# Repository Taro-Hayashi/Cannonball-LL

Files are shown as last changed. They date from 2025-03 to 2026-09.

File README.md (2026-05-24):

# Cannonball LL Build Manual ([日本語](https://note.com/taro_hayashi/n/n3da1e116aa8d))

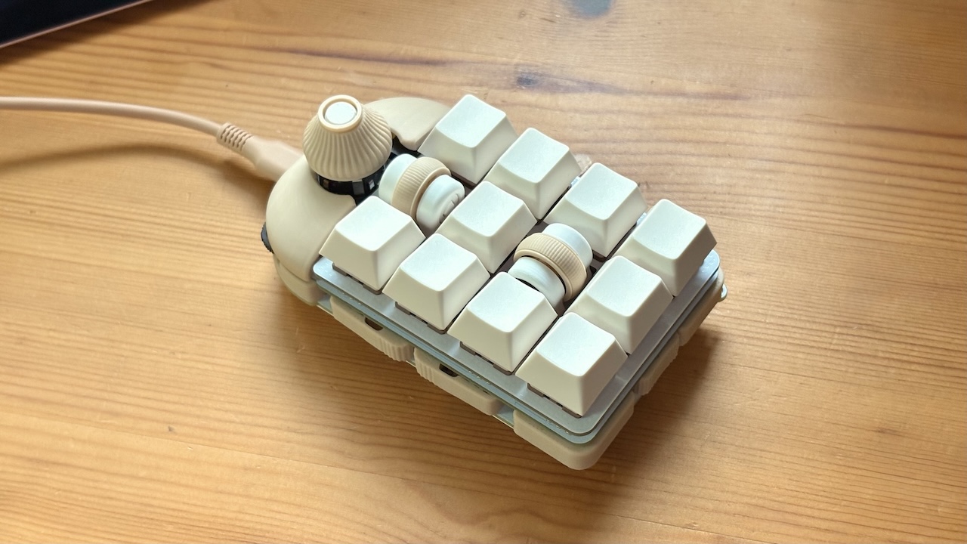
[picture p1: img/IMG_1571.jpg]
  

## 1 Introduction

### 1.1 Contents

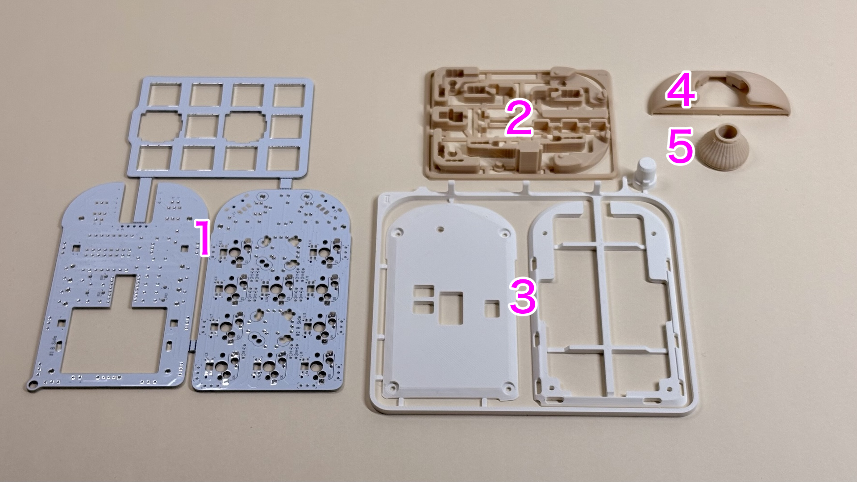
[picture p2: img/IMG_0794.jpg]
  
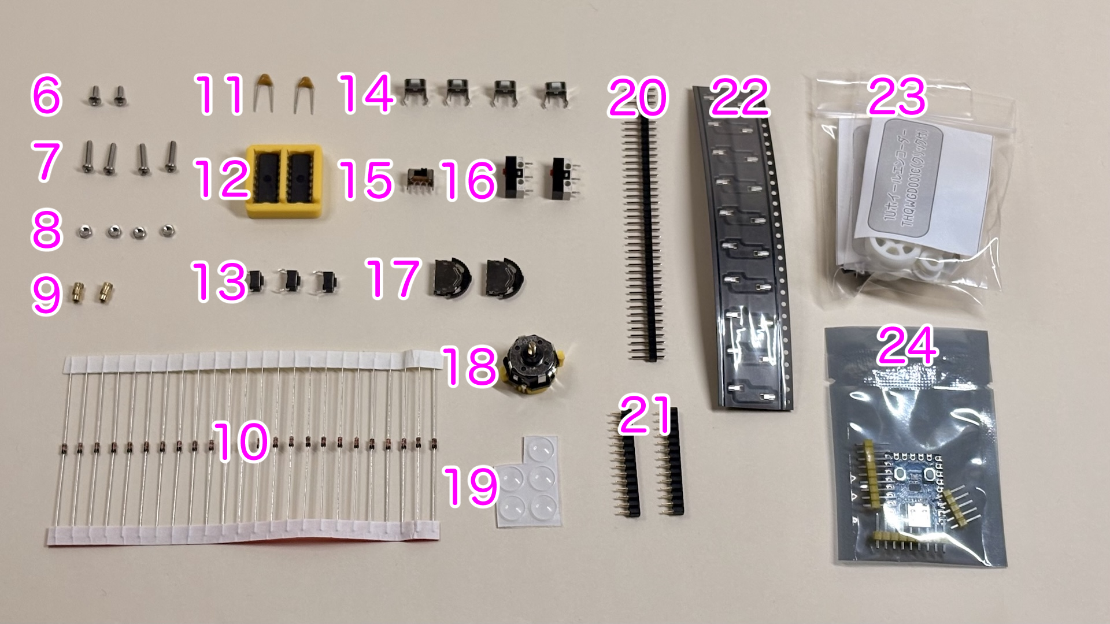
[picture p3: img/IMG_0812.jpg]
  

| | Types | Quantities | |
| --- | --- | --- | --- |
| 1 | PCB | 1 | |
| 2 | Runner I | 1 | |
| 3 | Runner II | 1 | |
| 4 | Top cover | 1 | |
| 5 | Knob cover | 1 | |
| 6 | Short screws | 2 | M2 6mm |
| 7 | Long screws | 4 | M2 10mm |
| 8 | Nuts | 4 | M2 |
| 9 | Insert nuts | 2 | M2 5mm or 6mm |
| 10  | Diodes | 24 | 1N4148 |
| 11  | Capacitors | 2 | 0.1uF |
| 12  | Shift registers | 2 | 74HC595 |
| 13  | back buttons | 3 | 3x6x4.3 |
| 14  | Side buttons | 4 | 3x6x5 |
| 15  | Slide switch | 1 | SK12F14 |
| 16  | Mouse buttons | 2 | YD-003 |
| 17  | Lever buttons | 2 | THMU27 |
| 18  | Rotary Encoder | 1 | RKJXT1F42001  |
| 19  | Rubber feet | 5 | |
| 20  | Pin header | 1 | 40pins |
| 21  | Pin Sockets | 2 | 14pins |
| 22  | Hotswap Sockets | 10 | CPG151101S11  |
| 23  | 1U Wheel Encoder | 2 | THQWGD001C |
| 24  | Micro Controller Board | 1 | RP2040-Zero |

### 1.2 Additional required

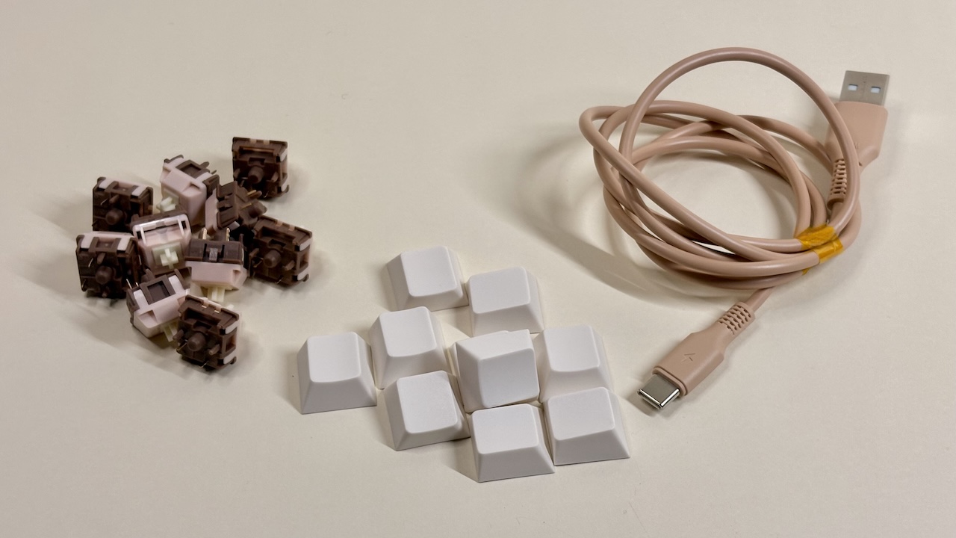
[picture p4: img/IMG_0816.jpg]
  

| Types | Quantities  |
| --- | --- |
| MX Keyswitches | 10  |
| Keycaps | 10  |
| Type-C USB cable | 1 |

### 1.3 Optional

See the guide below for more information on going wireless.
- [Cannonball LL Build Manual (wireless)](BLE.md)

| Types | Quantitie  | |
| --- | --- | --- |
| SK-6812MINI-E | 14  | |
| Choc V1/V2 keyswitches | 10  | Height can be reduced. Sockets and top plates are not used. It cannot coexist with MX switches. Not suitable for holding and using due to the possibility of short-circuiting as described below. |
| Tape or glue | 1 | When using Choc switches, isolate the head of the pin header to prevent unexpected operation. |
| [3-keys blocker](stl/) | 1 | Blocks the palm of the hand when held. |
| [Switch plate](stl/) | 1 | 3DP switch plate with invisible pin header heads. |
| Strap | | |

### 1.4 Tools required

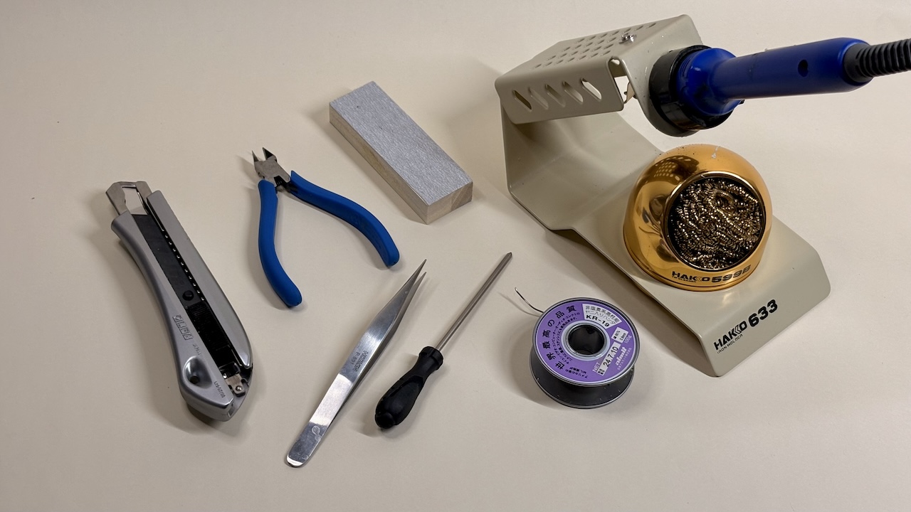
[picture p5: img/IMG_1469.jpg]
  

| Types                                                | 
| --------------------------------------------------- |
| Soldering iron                                               |
| Trowel                     |
| Soldering wire |
| Nipper                     | 
| Cutter                    |
| File                      | 
| Twezers                    |   
| screwdriver                 | 

### 1.5 Tools optional

| Types                               | 
| --------------------------------- | 
| C-type trowel tip                             | 
| flux|                    |
| IPA                               | 
| Heat-resistant mat                             | 
| Multimater                              |
| Desoldering wire                         | 
| Design Knife                           |
| Masking tape                          | 

## 2  Preparation for assembly

### 2.1 Disconnect the mainboard

It can be split cleanly by cutting a slit with a cutter and bending it.
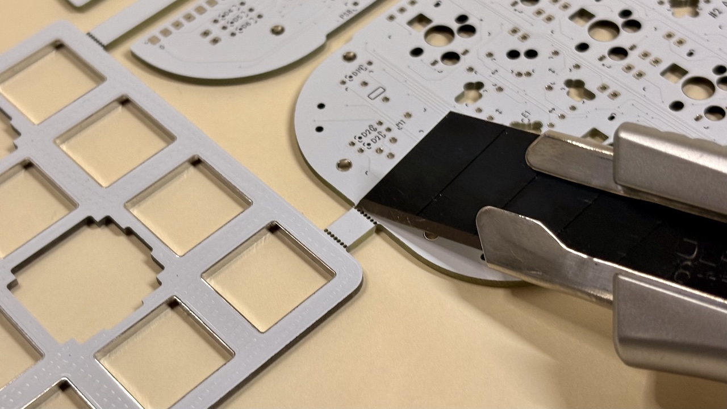
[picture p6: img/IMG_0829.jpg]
  
The tabs are cut away with nippers and the cut surfaces are sanded. Be careful not to remove the original board edges, as over-shaving will damage the circuitry.
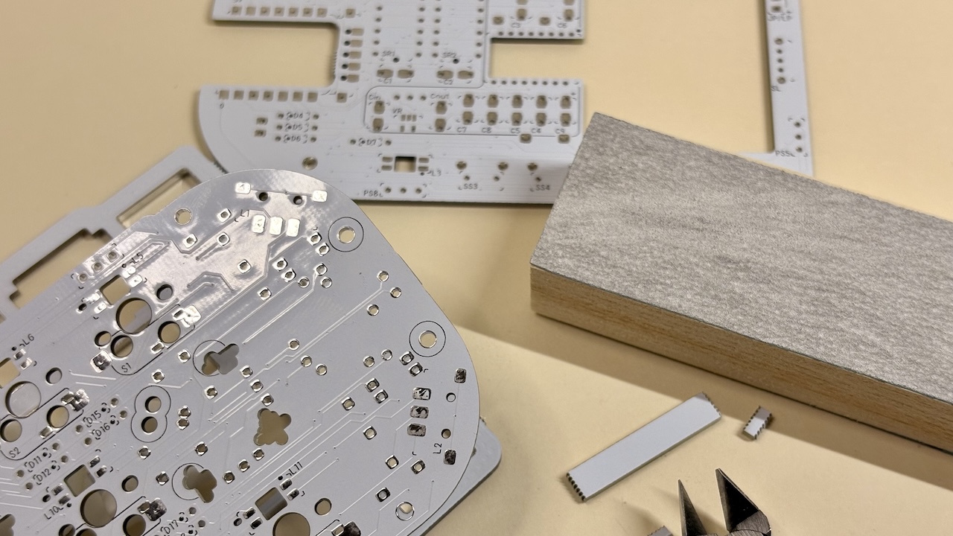
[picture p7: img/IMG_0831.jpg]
  
This area can be left jagged without affecting the finished form.
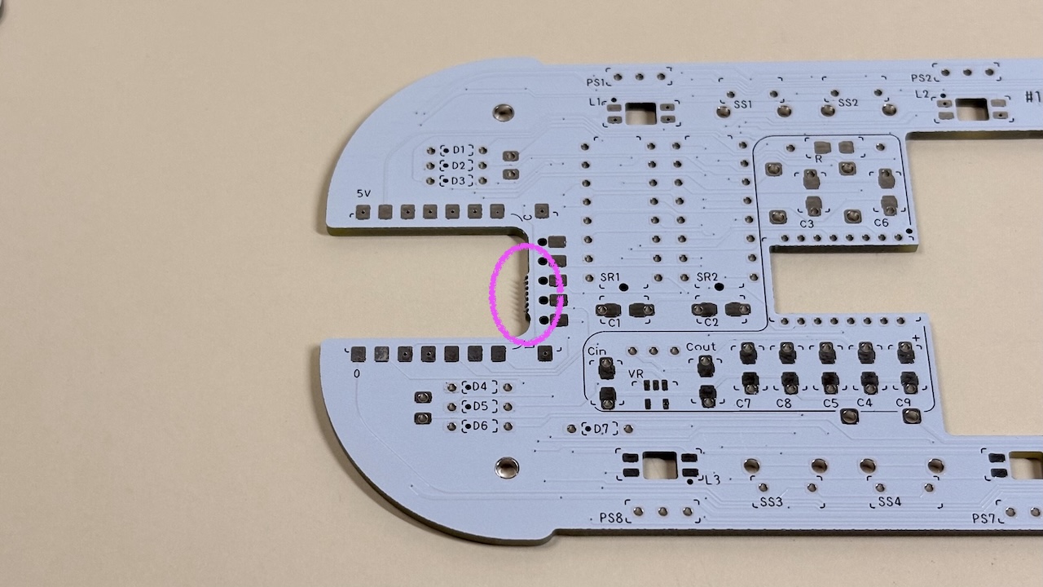
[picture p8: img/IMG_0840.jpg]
  
It could be divided into three parts: main board #1, main board #2 and switch plate.
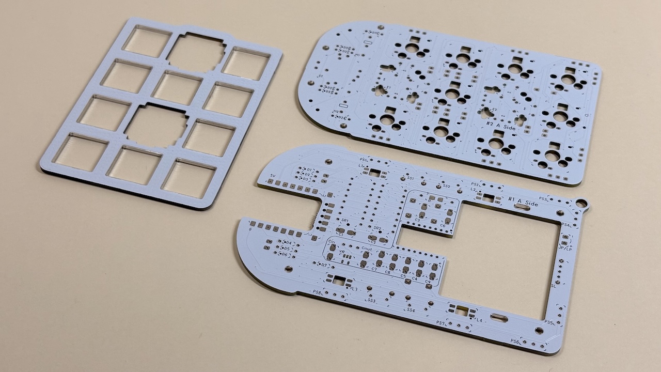
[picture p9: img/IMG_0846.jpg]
  

### 2.2 Remove parts from the runner

Runner I has 3 components and runner II has 17 components.
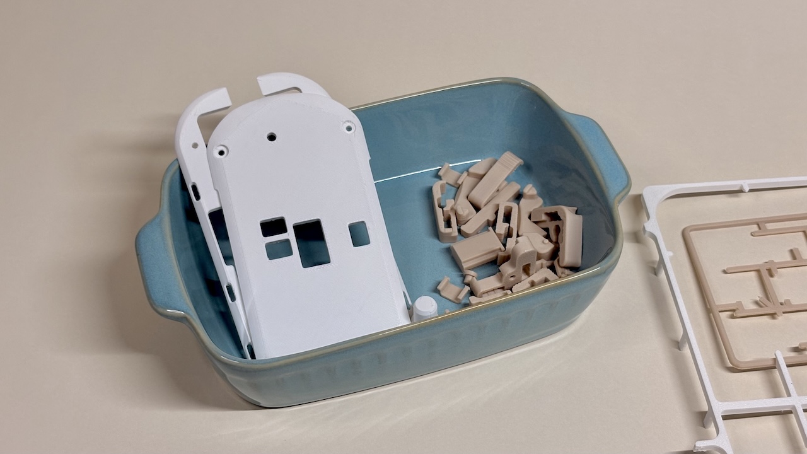
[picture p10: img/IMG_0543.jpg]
  

### 2.3 Remove the shift register and rotary encoder from the case

The shift register is pressed from the back with the runner II component (leverage). Be careful not to prick your finger with the pin.  
For the rotary encoder, cut the left and right claws with nippers.
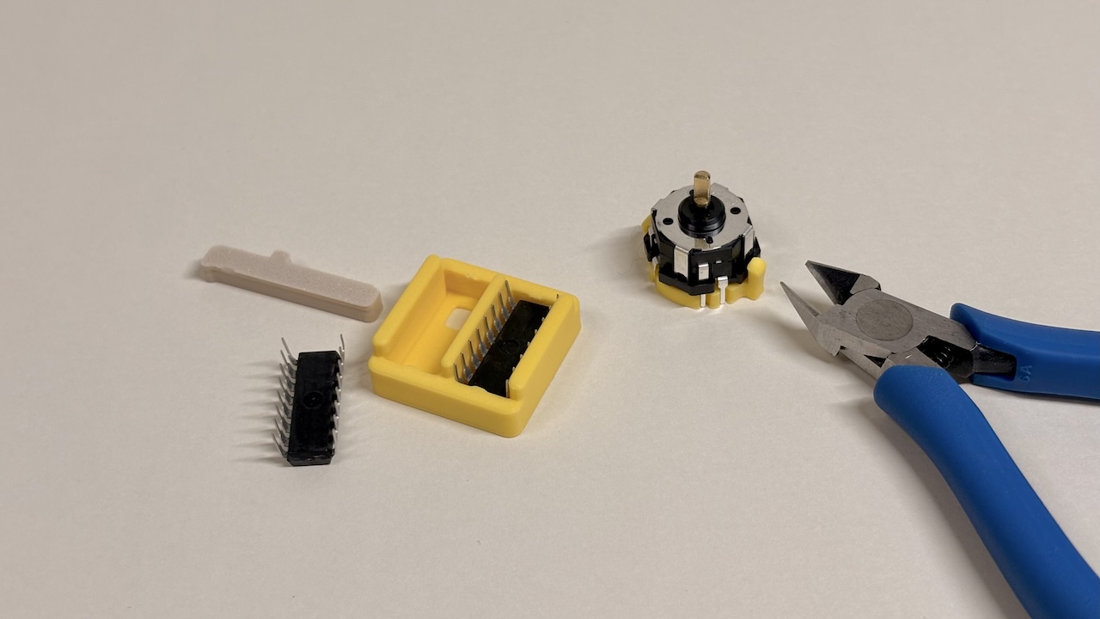
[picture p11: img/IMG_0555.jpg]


### 2.4 Write test firmware

Download the uf2 file here.

- [tarohayashi_cannonballll_default.uf2](https://github.com/Taro-Hayashi/Cannonball-LL/releases/latest/download/tarohayashi_cannonballll_default.uf2)

Connect to the PC via USB cable while pressing the BOOT button.
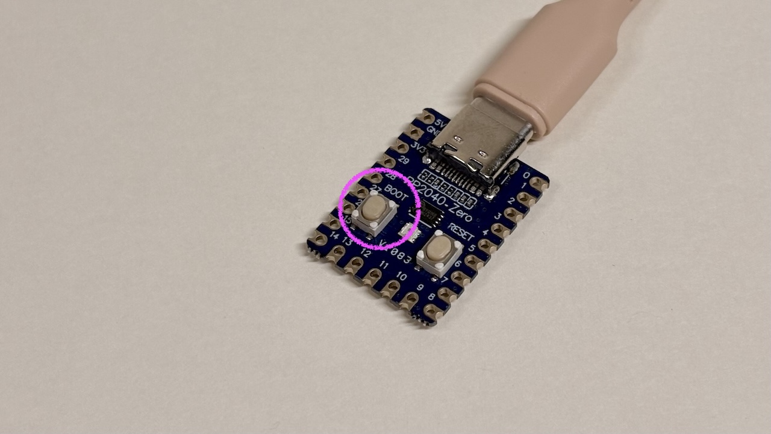
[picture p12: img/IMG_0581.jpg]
  
Drag and drop the uf2 file as it is recognised as an RPI-RP2 drive.  
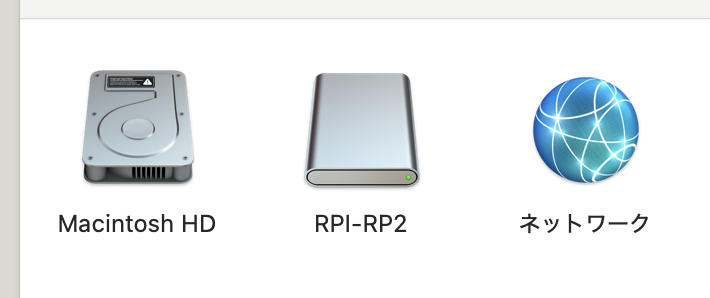
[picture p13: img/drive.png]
  
It will now be recognised as a keyboard.  

### 2.5 Press fitting of insert nuts

Press-fit the insert nut into the printed item in the image. Main board #1 is also used.
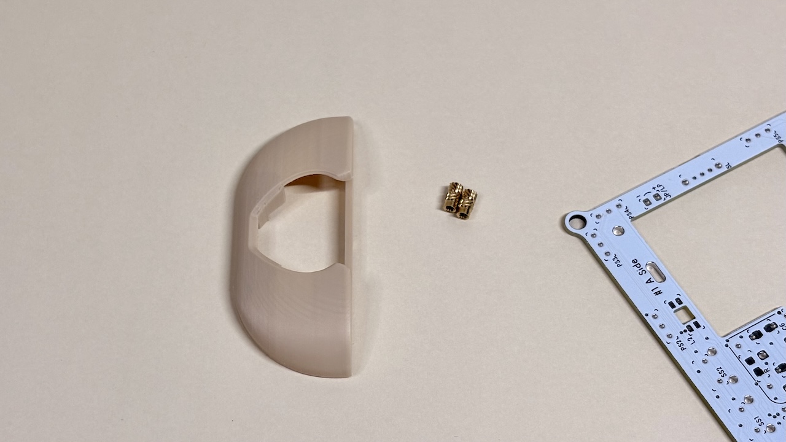
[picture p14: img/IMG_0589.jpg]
  
Apply main board #1 to the backside and press the soldering iron onto the insert nut.
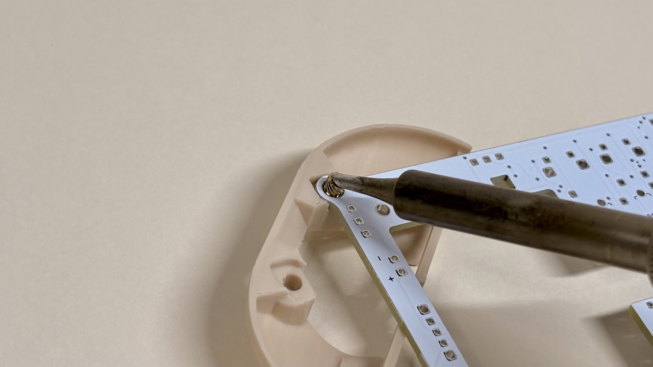
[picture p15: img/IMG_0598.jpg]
  
Ensure as few steps as possible with main board #1.
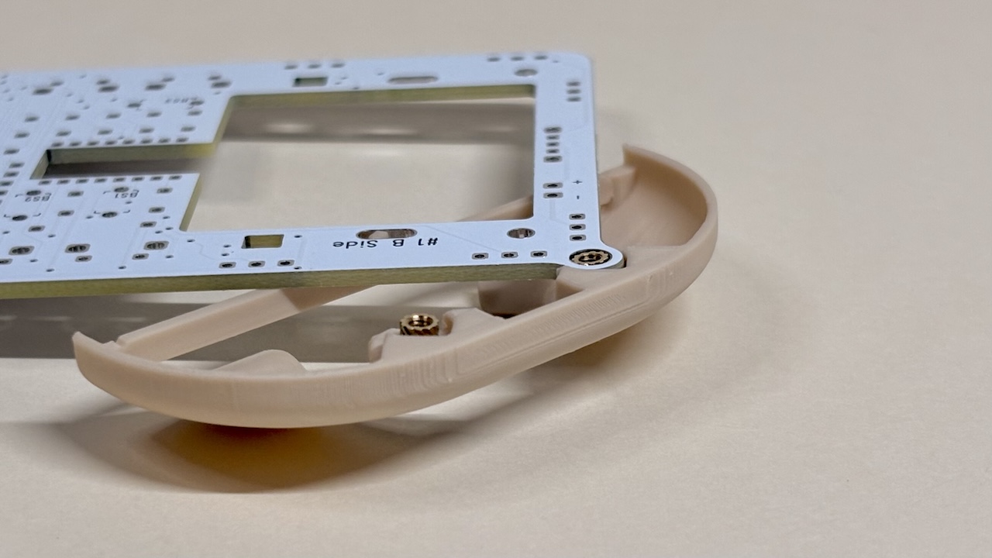
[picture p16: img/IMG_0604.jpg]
  
Cut out the reinforcement with nippers.
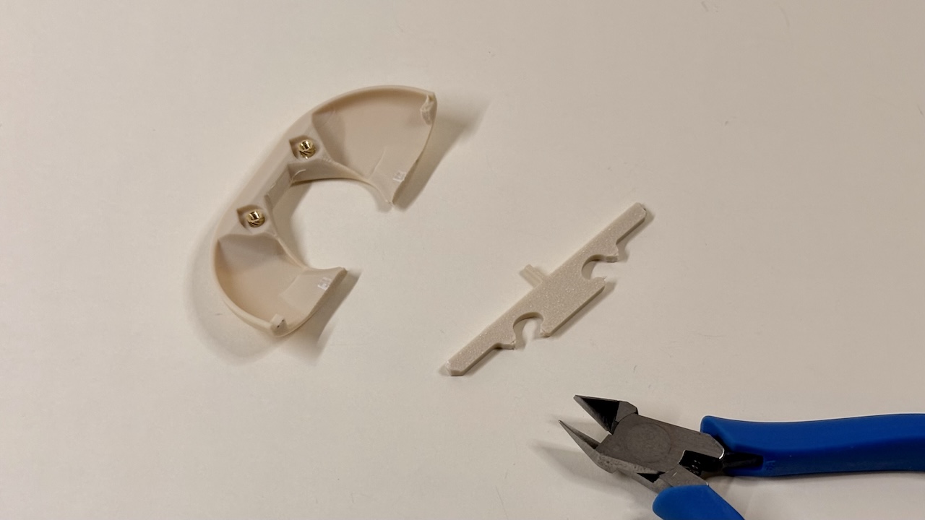
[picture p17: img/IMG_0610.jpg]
  

## 3 Soldering of main board #️1

### 3.1 Be careful when soldering

Imagine molten solder spreading only on the pad due to surface tension. It is very easy to apply flux.
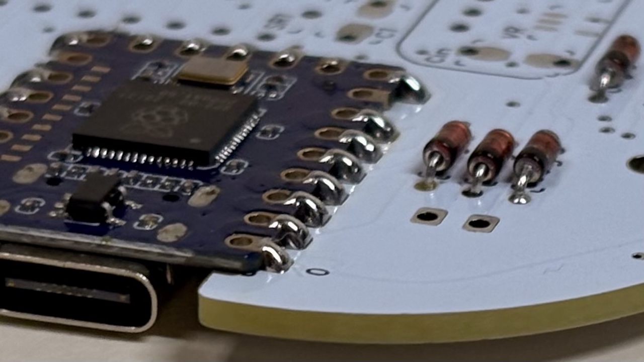
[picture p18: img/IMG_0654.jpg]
  
Heat the pads and component legs well to allow electricity to pass through both the board and the components.  
Be careful that the solder does not connect with the small holes (VIA).
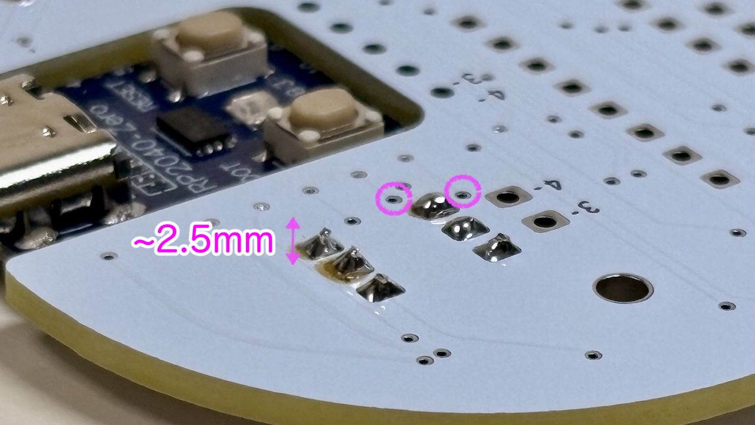
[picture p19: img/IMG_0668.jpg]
  
Take care that the legs coming out of the through-hole component are around 2 mm; if they exceed 2.5 mm, they may interfere with the 3D printed item on the bottom.  
It is easier to fix them with masking tape after insertion and soldering.
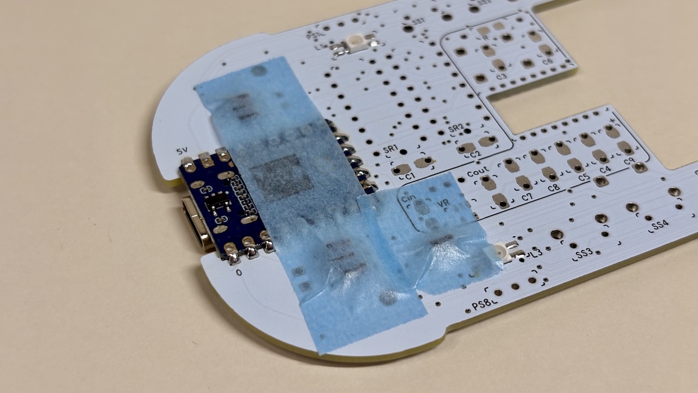
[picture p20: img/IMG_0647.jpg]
  
Also, the melting point of 3D printed products is around 200°C. Be careful not to melt the soldering iron if it comes into direct contact with it.

### 3.2 Soldering RP2040-Zero

Check the reverse side at 5V, GP0 and solder the 8 positions at the front once aligned using the pin headers supplied with the RP2040-Zero. Place a runner with the parts cut off underneath for stability.
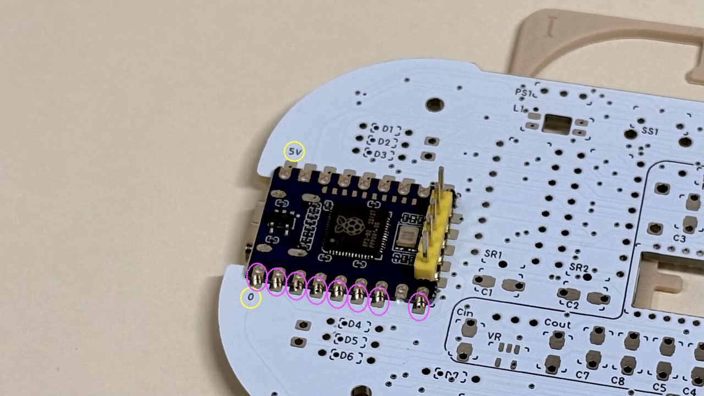
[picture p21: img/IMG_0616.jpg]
  
Once the other side is also soldered, remove the pin headers and solder the remaining five positions.
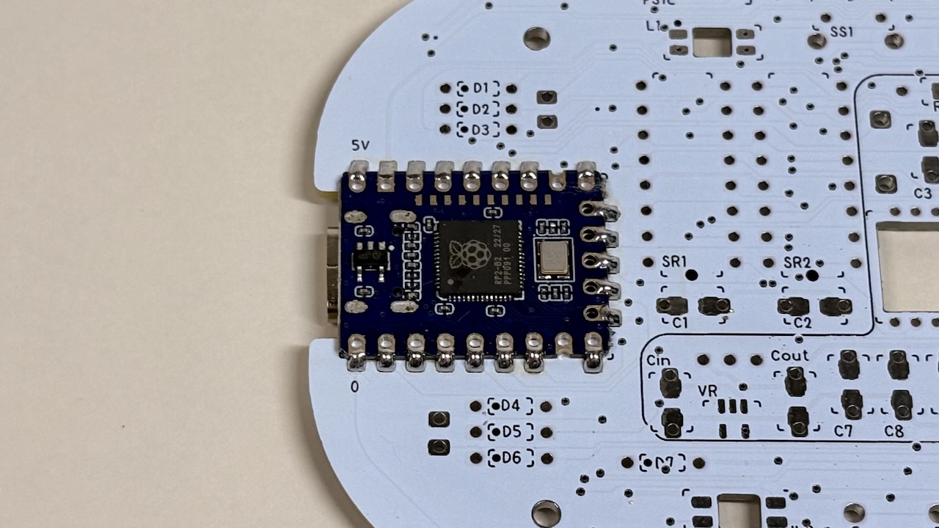
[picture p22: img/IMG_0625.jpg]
  

### 3.3 (Optional) Soldering the SK6812MINI-E

Solder L1 to L4, aligning the mark with the missing direction.
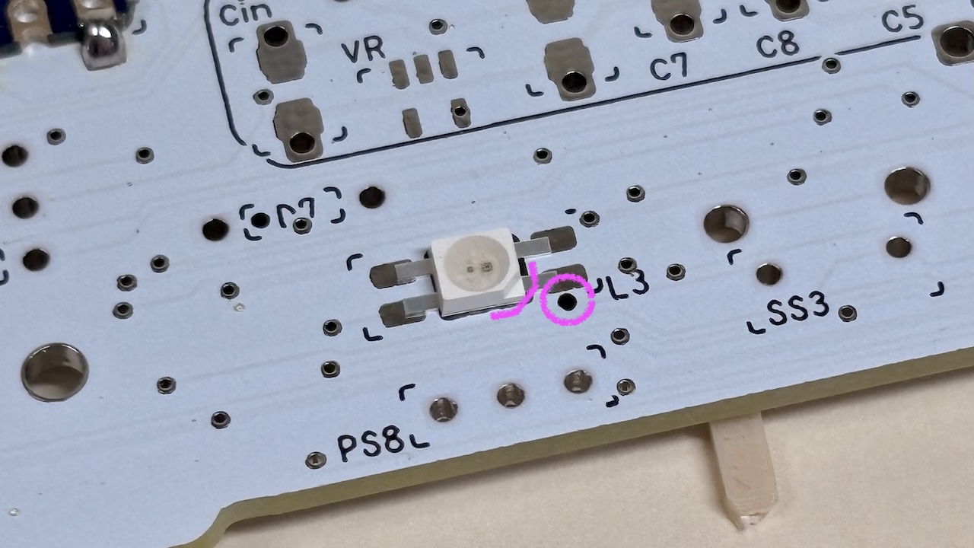
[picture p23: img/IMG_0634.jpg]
  
The luminous surface is facing you.
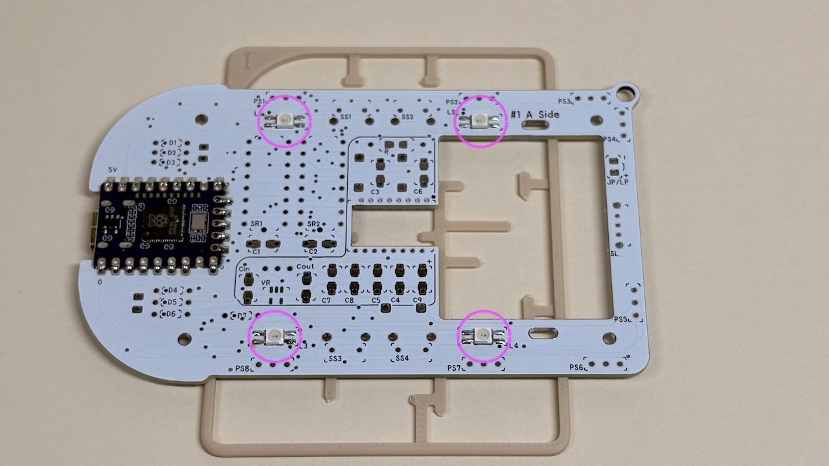
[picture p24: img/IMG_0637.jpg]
  

### 3.4 Soldering of diodes

The diode has a direction. Align the mark with the direction of the black line.
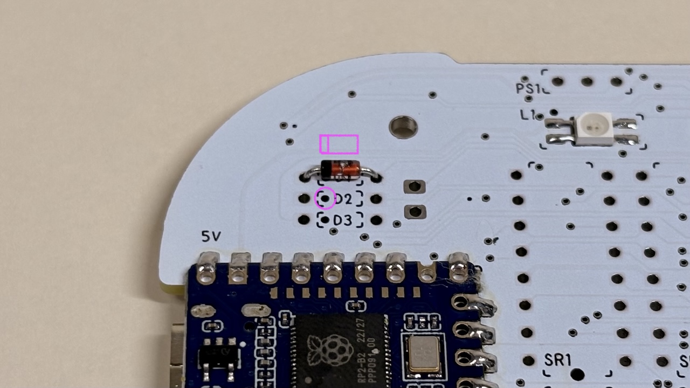
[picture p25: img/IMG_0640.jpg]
  
Insert the diode into D1, turn it over, solder it and cut the legs with nippers.
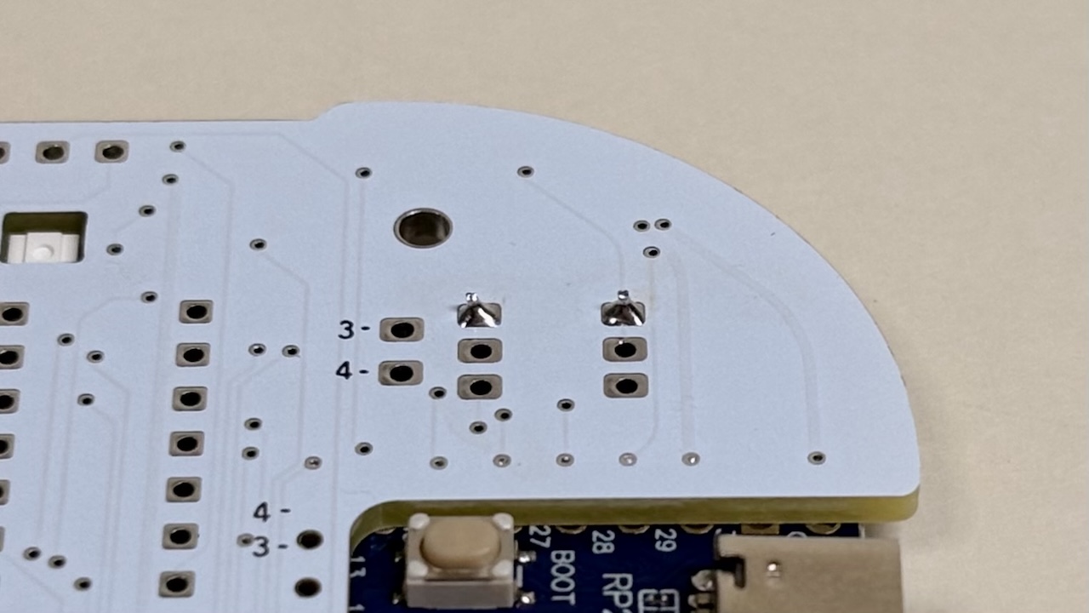
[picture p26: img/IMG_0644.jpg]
  
Solder 7 places up to D7.
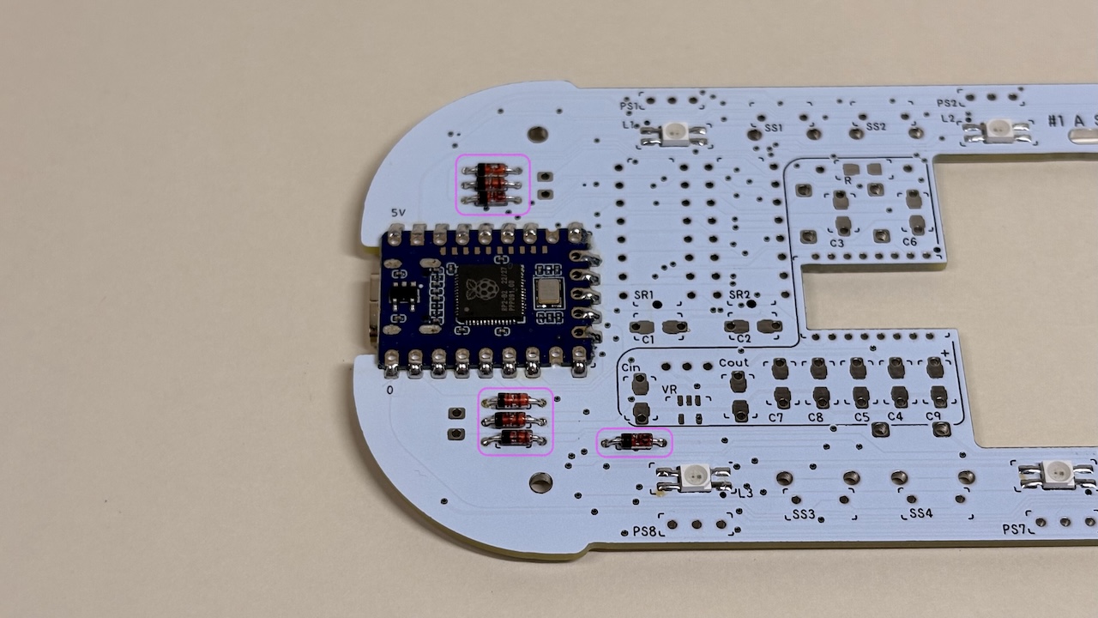
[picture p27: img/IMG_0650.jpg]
  
Leave one leg.
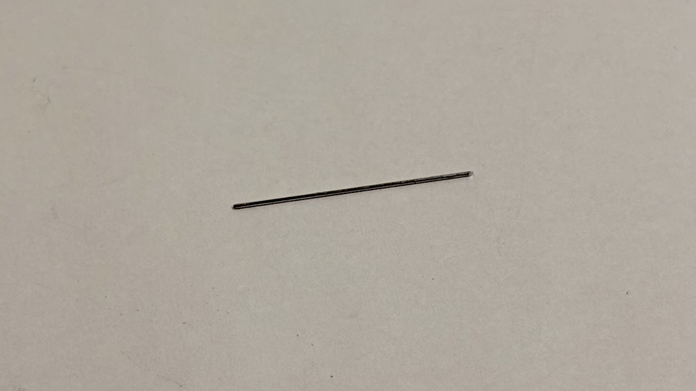
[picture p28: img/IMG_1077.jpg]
  

### 3.5 Soldering of shift registers

Insert the legs into SR1 and SR2 without breaking them, and solder them after checking that all the legs are sticking out from the back.  
Align the circle mark with the direction of the chip on the package.
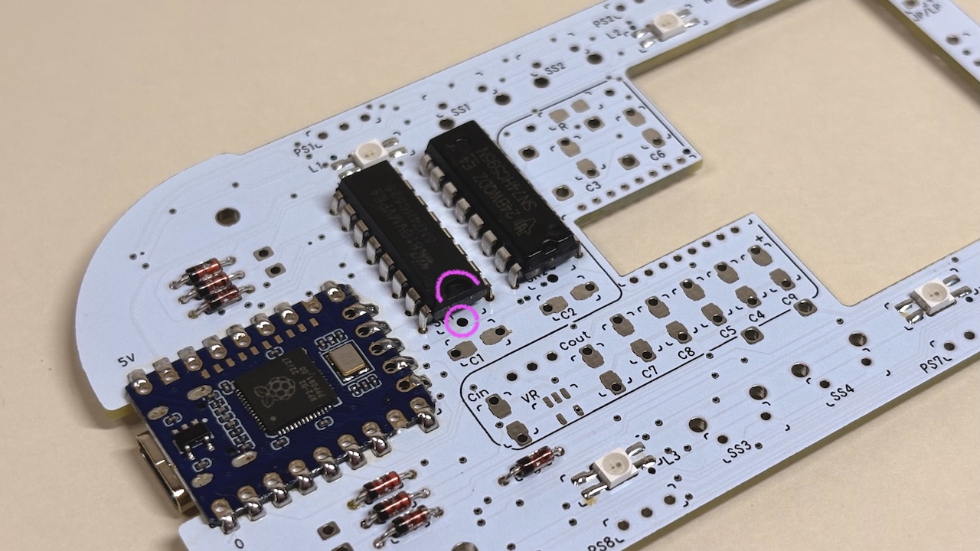
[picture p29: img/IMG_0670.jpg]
  

### 3.6  Soldering of capacitors

Solder to C1 and C2.  
Make sure it says 104. If it is not, this is a packaging error and this step should be skipped. The capacitor will work without it.
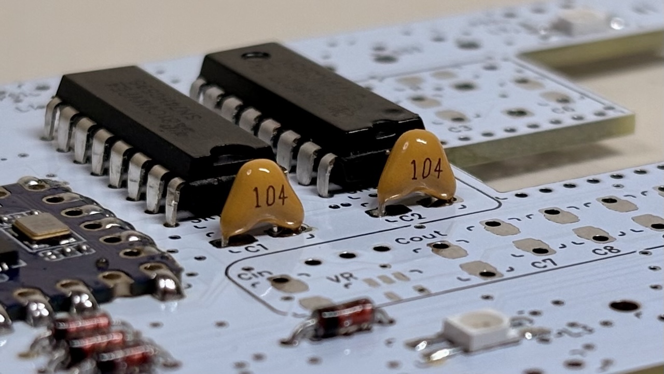
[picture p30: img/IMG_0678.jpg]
  

### 3.7 Soldering side buttons and slide switches

Plug and solder the four side buttons SS1 to SS4 and one slide switch to SL.
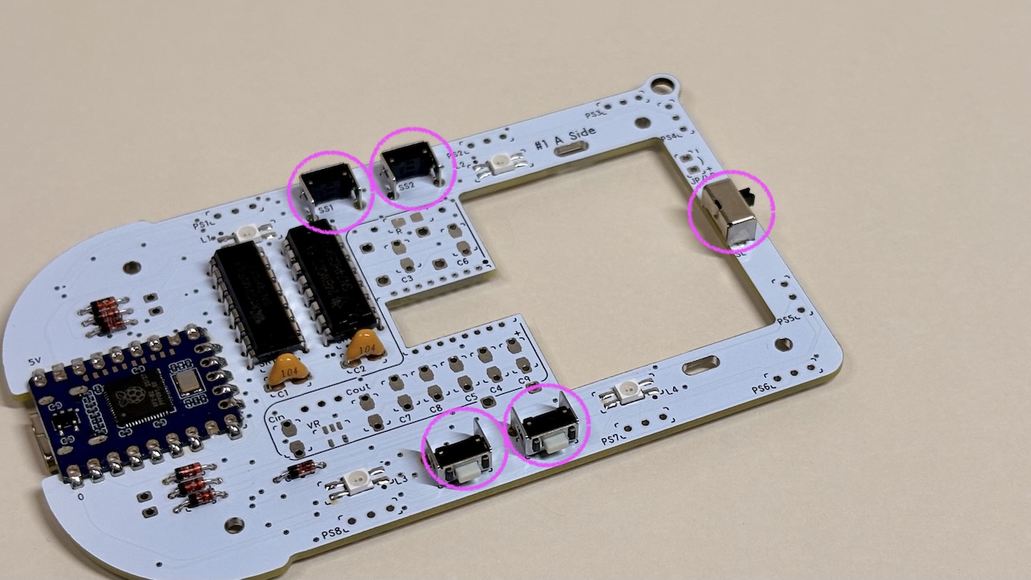
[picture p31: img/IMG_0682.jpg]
  

### 3.8 Jumper short circuit
Bend the legs of the diode you have taken away into a U-shape.
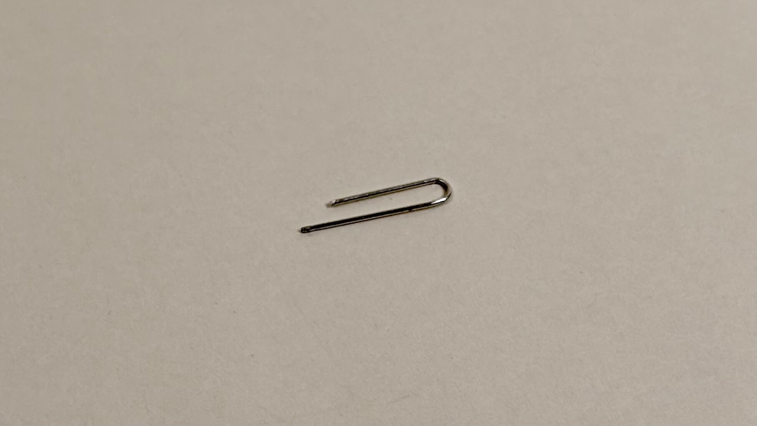
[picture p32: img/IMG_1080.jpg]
  
Short-circuit JP/LP next to the slide switch.
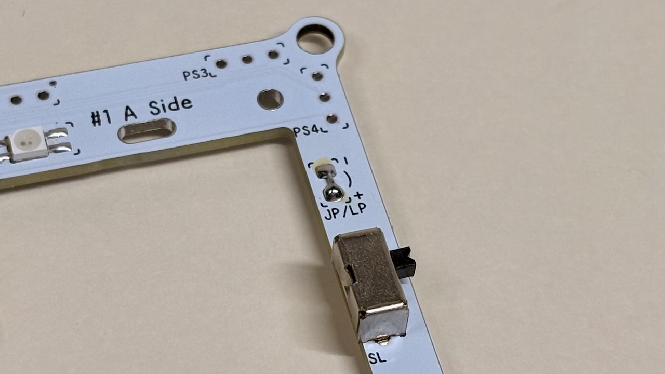
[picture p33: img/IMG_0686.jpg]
  

### 3.9 Soldering of back buttons

The back button is inserted from the backside.
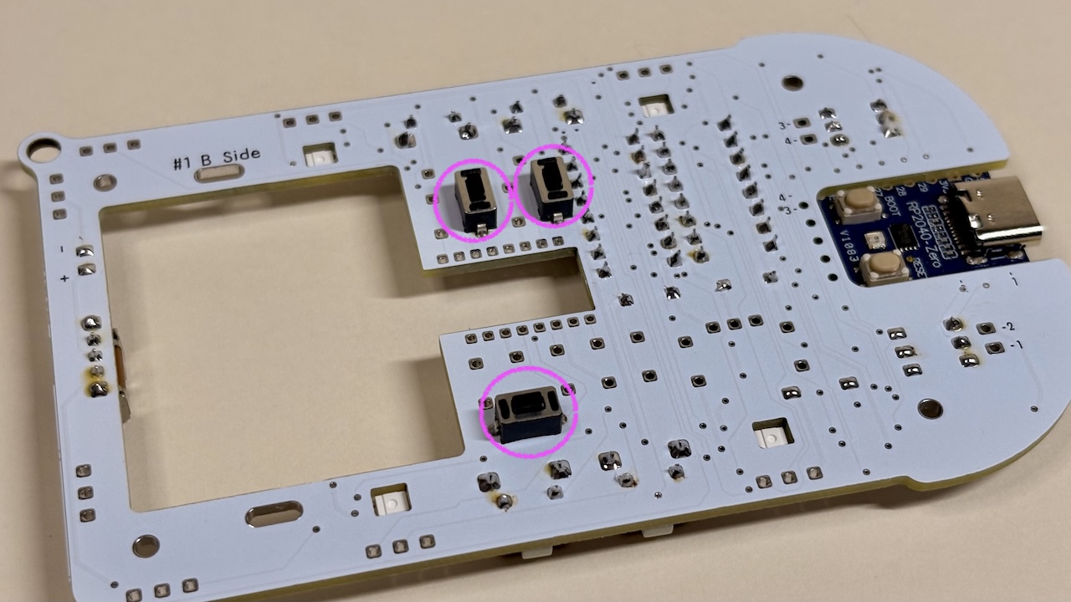
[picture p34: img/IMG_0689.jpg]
  

### 3.10  Confirmation of operation

Connect to a PC via USB cable and check the operation of the side and rear buttons; if 8 continues to be entered, switch the slide switch.
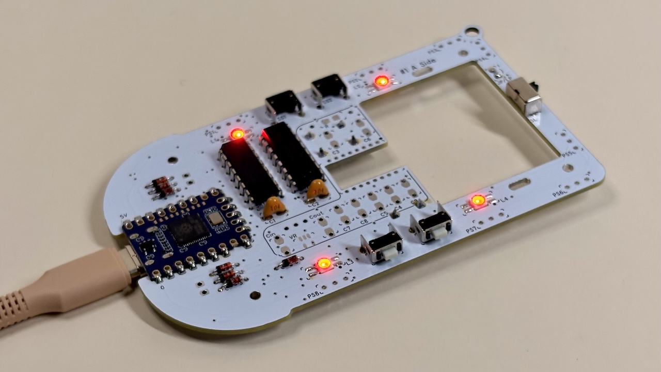
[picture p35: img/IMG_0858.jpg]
  
After checking, disconnect the cable. Soldering with the power on may cause a fault.

### 3.11 Soldering of pin sockets

Cut out eight pin sockets and pin headers with three pins each.
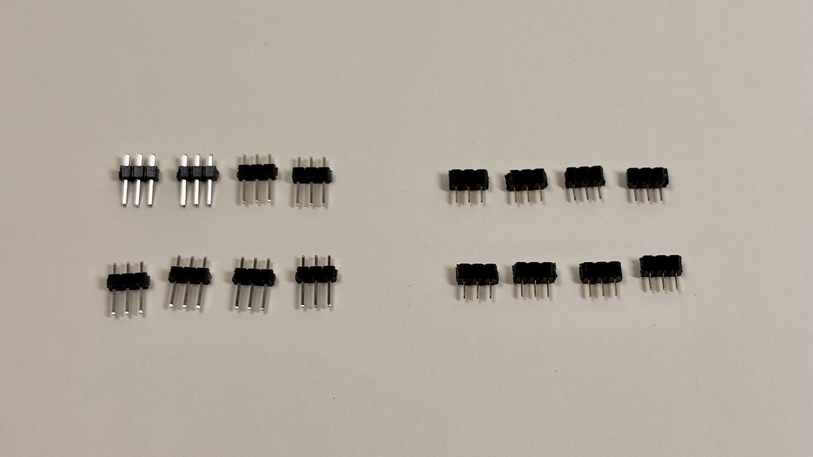
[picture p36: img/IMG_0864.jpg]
  
Insert the short end of the pin header into the pin socket and place the pin socket side on main board #1.
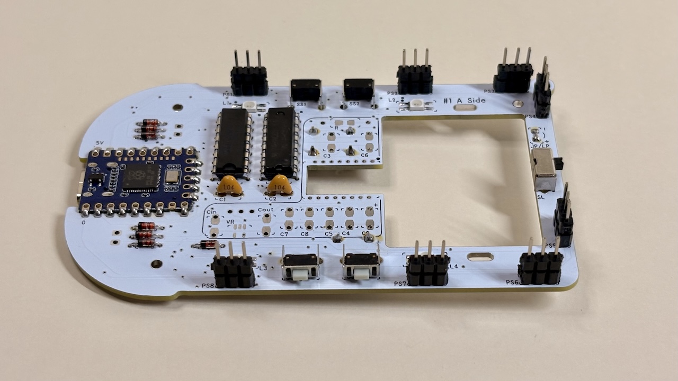
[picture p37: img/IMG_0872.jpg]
  
Insert the six Runner II components. If they are difficult to insert, shave off the cut marks on the pin headers or pin sockets.
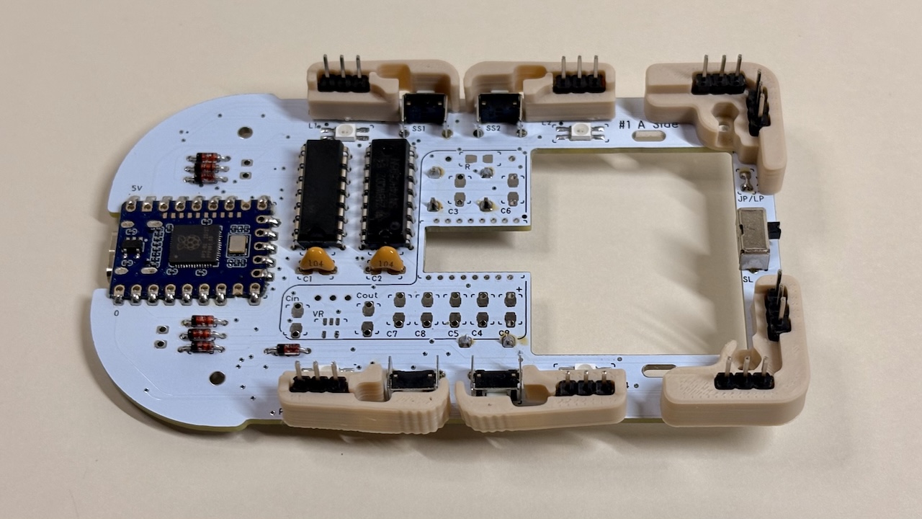
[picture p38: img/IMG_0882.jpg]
  
Cover the main board #2 with the pin headers (do not solder yet). If it is difficult to get all the pin headers through, force a few at a time to avoid rubbing the board.
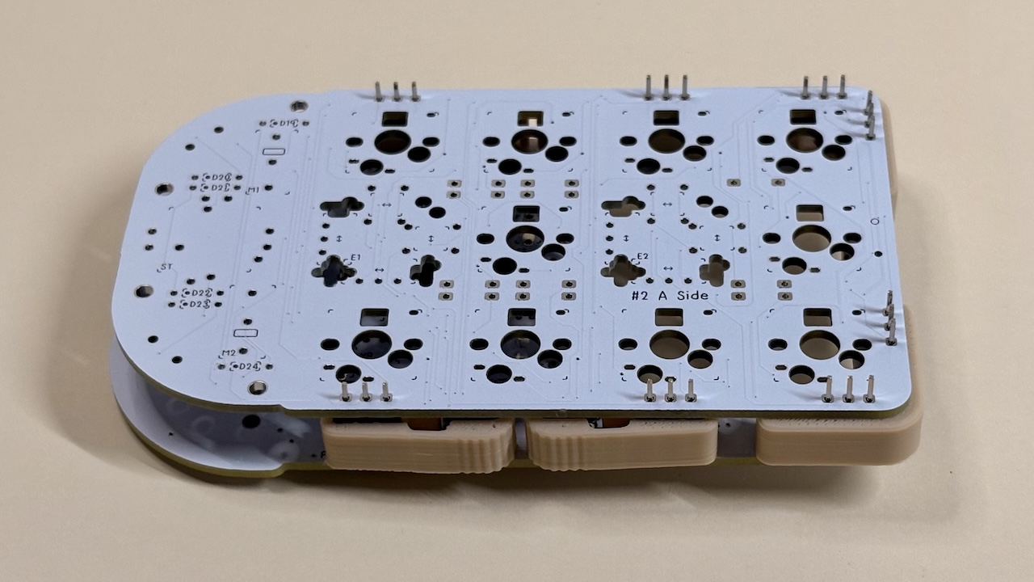
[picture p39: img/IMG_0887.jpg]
  
Once flipped over, solder the pin socket to main board #1.
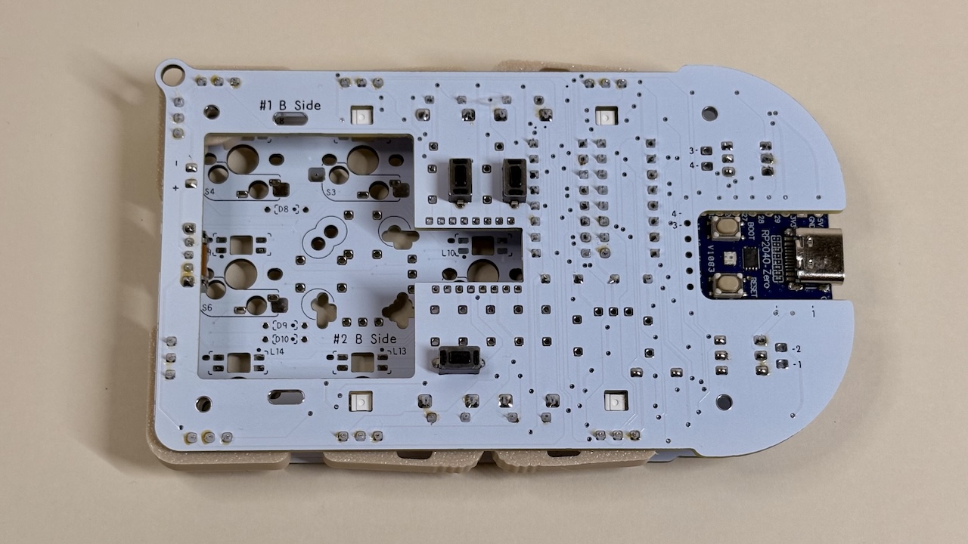
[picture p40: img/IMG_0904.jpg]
  
After soldering is complete, return to the front and remove main board #2.  
Printed items do not need to be removed.
  
If mainboard #2 has been soldered in place, use leverage to remove it. Be aware that if the pin header is bent, it may cause poor contact, so pull it out vertically.
  
If a multimater is available, check that there is continuity between the GPIO and pin headers of the RP2040-Zero and shift register.
  

## 3.12 Assembling the lower half
Combine the parts of runner I and place five parts of runner II. Pay attention to the orientation of the central component.
  
Place mainboard #1 on top and fit a nut on one of the corner components of runner I.
  
A total of 9 runner I components and 4 nuts were fitted with long screws.
  

## 4 Soldering of mainboard #2

### 4.1 (Optional) Soldering the SK6812MINI-E

Solder from L5 to L14. On main board #2, the light-emitting surface faces the other way.
  

### 4.2 Soldering of diodes

Solder D8 to D24; from D19 onwards the mounting surface is different.
  
  

### 4.3 Soldering of MX sockets

Solder from S1 to S10. The amount of solder required for the socket is greater.
  

### 4.4  Soldering of lever buttons

Attach to L1 and L2. Solder the contacts on the sides as well.
  

### 4.5 Soldering of mouse buttons

Attach to M1 and M2. Align the click bar with the silk print.
  

### 4.6 Assembling the 1U wheel encoder

The following components of the sachet are used.
  

| | Types | Quantities| |
| --- | --- | --- | --- |
| 1 | Wheel | 2 | |
| 2 | Shaft | 2 | |
| 3 | Spacer | 2 | |
| 4 | Base | 2 | |
| 5 | Cover | 2 | |
| 6 | Wheel Encoder | 2 | 6x6x7 |
| 7 | tactile Button | 2 | 11mm |
| 8 | Short screws | 4 | M2 5mm or 6mm |
| 9 | Nut | 4 | M2 |

Solder the tactile button and wheel encoder to E1 and E2 in the orientation chosen. The build guide uses the orientation shown in the image.
  
Insert the shaft from the flat side of the wheel.
  
Attach the wheel to the encoder. Ensure that the hexagonal holes align with the hexagonal shaft.
  
Fit the spacer and place it on the tactile button.
  
Attach the base with screws and nuts.
  
Install the cover.
  

### 4.7 Soldering rotary encoders

Solder to ST.
  

### 4.8 Installing the top cover

Attach from the rear side with short screws.
  
Ensure that the mouse buttons are clickable.
  

### 4.9 Soldering of pin headers

Once again, check the orientation and soldering of the components on mainboard #2.  
If everything looks OK, put it on mainboard #1 and solder the pin headers.
  
Working one by one, starting with the corner pin headers, while trying to reduce the gaps as much as possible, will produce a clean result.

### 4.10 Checking the operation

Attach the shaft from Runner I to the rotary encoder.
  
Connect to a PC to check operation. Check the operation of the socket with one of the keyswitches. Be careful not to break the leg of the keyswitch.
  
After checking operation, disconnect the USB cable.

### 4.11 Installing the switch plate
Align the switch plate with main board #2 and install the keyswitch.
  
Once all 10 pieces are fitted, attach the rubber feet.
  
The keycap and knob cover are completed when fitted.
  
From here, the work is done using a PC.

## 5 Customise

### 5.1 Replacing keys with Remap.

Connect to Remap and select Customise.

- remap https://remap-keys.app/

  
Continue on and select Cannonball LL.
  
Drag and drop from the key list below and press the write button in the top right corner to swap keys.
  
You can also set simultaneous presses with modifier keys by clicking on the key.

### 5.2 Rotary encoder settings
Click on the direction of rotation to switch the key to be registered.
  
The leading rotary encoder push-in is disabled.

### 5.3 (Optional) LED adjustment.
The luminescence can be adjusted via the icons in the image.
  

### 5.4 Special keys
In addition to the standard functions provided in Remap, there are special shortcuts and configuration keys on the Functions tab.
  

| Key name | Keycode | |
| --- | --- | --- |
| Cmd / Ctrl  | CMD_CTL | Control（Windows） / Command（MacOS、iOS） |
| Undo | UNDO | Cmd / Ctrl + Z |
| Redo | REDO | Cmd / Ctrl + Shift + Z |
| Copy | COPY | Cmd / Ctrl + C |
| Cut | CUT | Cmd / Ctrl + X |
| Paste | PASTE | Cmd / Ctrl + V |
| Scale Up | SC_UP | Cmd / Ctrl + + |
| Scale Down  | SC_DOWN | Cmd / Ctrl + - |
| Scale Reset | SC_RESET | Cmd / Ctrl + 0 |
| Captcha | CAPTCHA | Win + Shift + 4 / Command + Shift + 4 |
| Save | SAVE | Cmd / Ctrl + S |
| Save As | SAVEAS | Cmd / Ctrl + Shift + S |
| Close Tab | CLOSETAB | Cmd / Ctrl + W |
| Restore Tab | RSTRTAB | Cmd / Ctrl + Shift + T |
| Next App | NEXTAPP | Cmd / Ctrl + |
| Prev App | PREVAPP | Cmd / Ctrl + |
| RGB Layers  | RGB_LAYERS | On/off functionality to change the colour of the LEDs layer by layer. |

## 6 Misc

### 6.1 Maintenance

If the knob becomes loose or the 1U wheel encoder cover comes off easily, it can be adjusted and fixed by melting it with a soldering iron.  
If the top and bottom fastenings become loose or poor contact, consider replacing the pin headers and pin sockets.

### 6.2 Data for 3D Printing

- [Data for 3D Printing](/stl)

Optional or colour-changed parts can be printed.
  
  
### 6.3 Firmware code

- [keyboards/tarohayashi/cannonballll](qmk_firmware)

### 6.4 Firmware for VIAL

-[tarohayashi_cannonballll_vial.uf2](https://github.com/Taro-Hayashi/Cannonball-LL/releases/download/0.28.2/tarohayashi_cannonballll_vial.uf2)

### 6.4 Thanks

I referred to snize([@snize](https://x.com/snize))'s SEIBOKU for the selection of components and the firmware code of PMW3610.

- https://github.com/snize/BOB-PMW3610-SEIBOKU

### 6.5 Sales
- Yushakobo: https://shop.yushakobo.jp/en/products/10537
- Booth: https://tarohayashi.booth.pm/items/6736492

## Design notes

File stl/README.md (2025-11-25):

# Data for 3D Printing

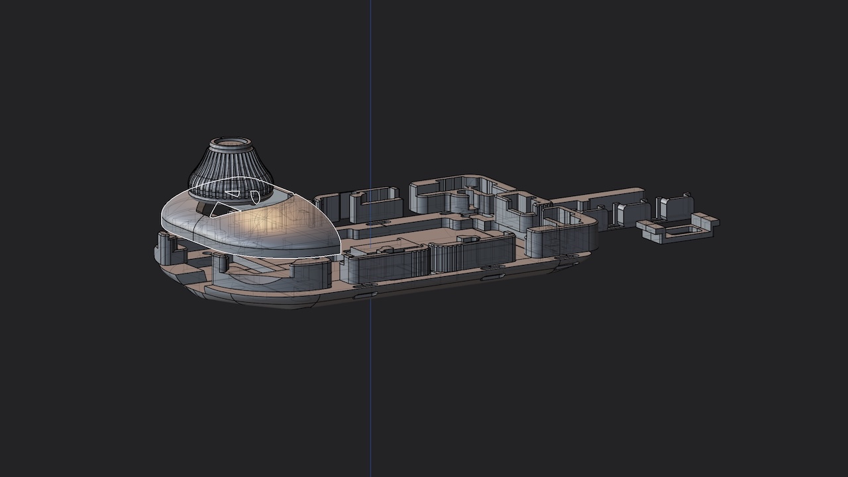
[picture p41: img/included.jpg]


<a href="https://github.com/Taro-Hayashi/Cannonball-LL/">Cannonball LL</a> © 2025 by <a href="https://x.com/w_vwbw">Taro Hayashi</a> is licensed under <a href="https://creativecommons.org/licenses/by-nc-sa/4.0/">CC BY-NC-SA 4.0
</a></p>

## Optional parts

| File name      |
| -------------- |
| Switch plate   |
| 3-Keys Blocker |
| Mech knob      |
| integrated Bottom            |
| integrated Sensor cover      |

## Included parts
| File name         |
| ----------------- |
| Bottom #1,2       |
| Side #1 - #9      |
| Top cover         |
| Shaft             |
| Knob              |
| Bottom button     |
| Reset button      |
| leverage          |
| Sensor cover #1,2 |
| Blocker           |

## 1U Wheel Encoder THQWGD001
- https://github.com/Taro-Hayashi/THQWGD001

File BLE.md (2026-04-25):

# Cannonball LL Build Manual (wireless) ([日本語](https://note.com/taro_hayashi/n/n1ee5ece46387))

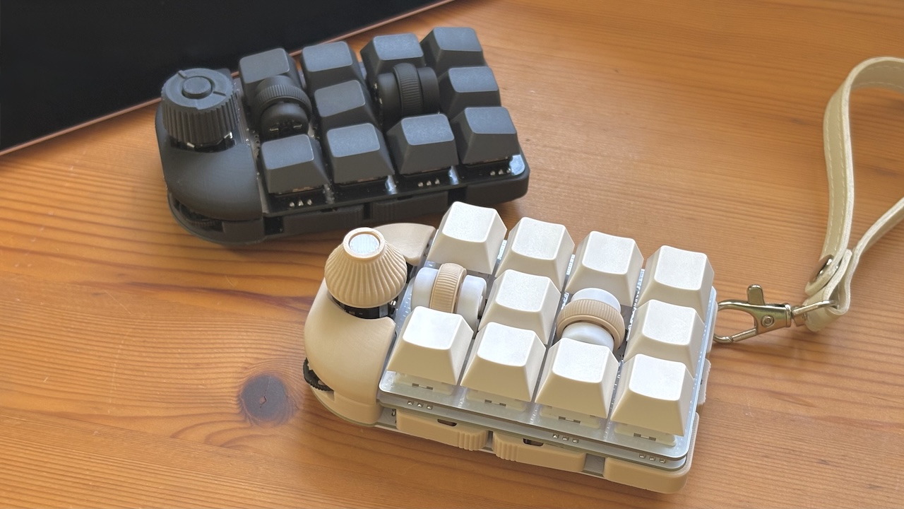
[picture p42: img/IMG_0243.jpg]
  

## 1 Introduction

### 1.1 Attention

- Lithium polymer batteries can explode and cause injury or fire, so handle them with care when in use.

### 1.2 Contents

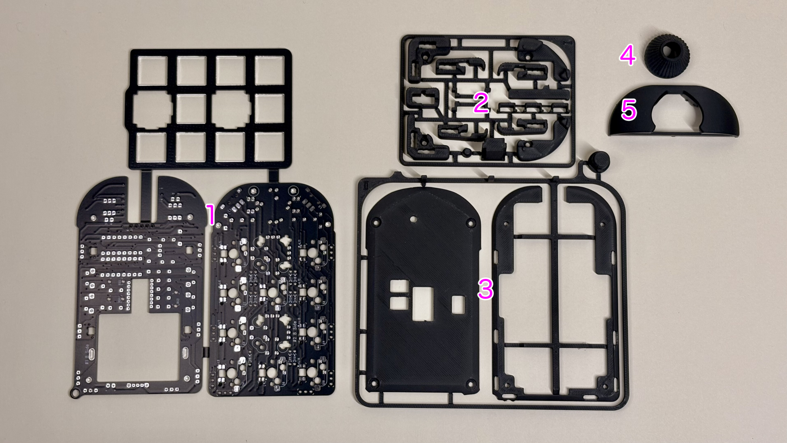
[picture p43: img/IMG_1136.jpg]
  
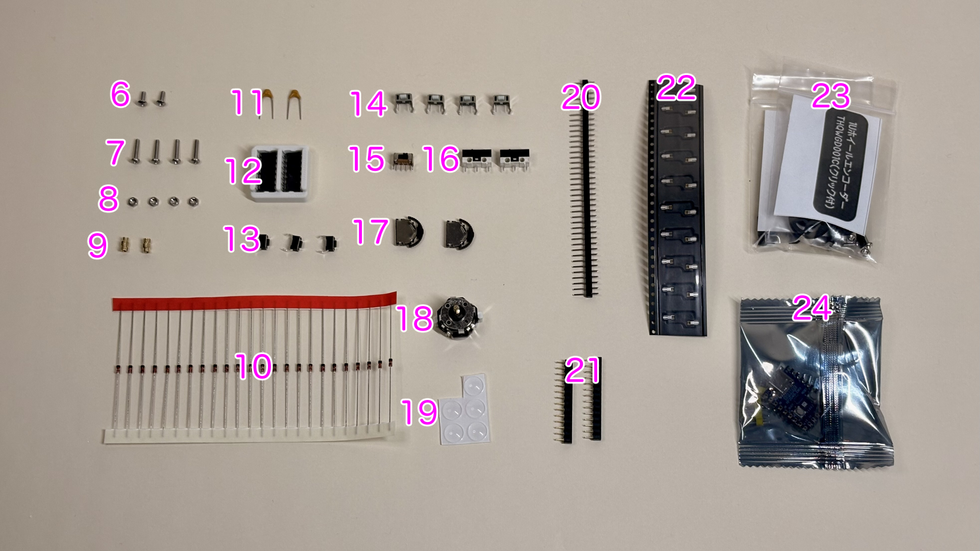
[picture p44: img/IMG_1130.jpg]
  

| | Types | Quantities | |
| --- | --- | --- | --- |
| 1 | PCB | 1 | |
| 2 | Runner I | 1 | |
| 3 | Runner II | 1 | |
| 4 | Top cover | 1 | |
| 5 | Knob cover | 1 | |
| 6 | Short screws | 2 | M2 6mm |
| 7 | Long screws | 4 | M2 10mm |
| 8 | Nuts | 4 | M2 |
| 9 | Insert nuts | 2 | M2 5mm or 6mm |
| 10  | Diodes | 24 | 1N4148 |
| 11  | Capacitors | 2 | 0.1uF |
| 12  | Shift registers | 2 | 74HC595 |
| 13  | back buttons | 3 | 3x6x4.3 |
| 14  | Side buttons | 4 | 3x6x5 |
| 15  | Slide switch | 1 | SK12F14 |
| 16  | Mouse buttons | 2 | YD-003 |
| 17  | Lever buttons | 2 | THMU27 |
| 18  | Rotary Encoder | 1 | RKJXT1F42001  |
| 19  | Rubber feet | 5 | |
| 20  | Pin header | 1 | 40pins |
| 21  | Pin Sockets | 2 | 14pins |
| 22  | Hotswap Sockets | 10 | CPG151101S11  |
| 23  | 1U Wheel Encoder | 2 | THQWGD001C |
| 24  | Micro Controller Board | 1 | RP2040-Zero |

### 1.3 Additional required
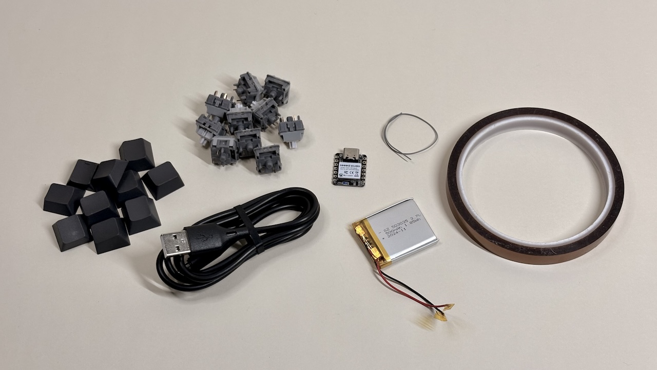
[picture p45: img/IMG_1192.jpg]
  

| Types | Quantities  |
| --- | --- |
| MX Keyswitches | 10  |
| Keycaps | 10  |
| XIAO BLE | 1 |
| Lead wire | 1 |
| LiPo battery | 1 |
| Protective tape, rubber sheeting, etc. | 1 |

### 1.4 Further additional required to a wireless mouse
Capacitors and resistors are available in leaded or 1206 and 0805 packages.
The regulator can be TO92 or SOT23-5. The image shows the sensor set on BOOTH.

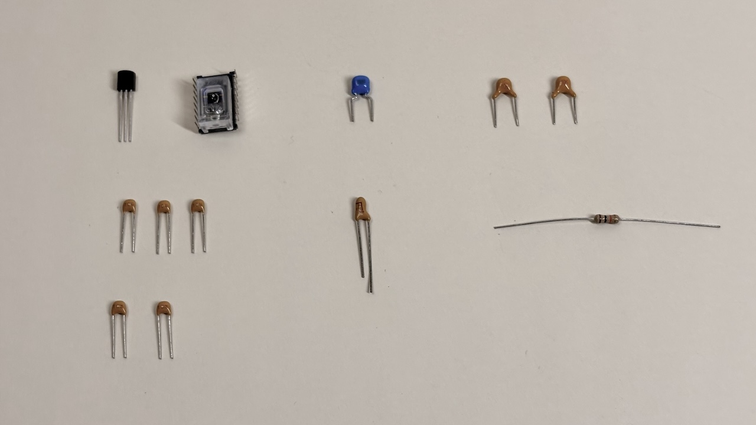
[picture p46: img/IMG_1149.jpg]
  

| | Types | Quantities  | | 
| --- | --- | --- | --- |
| | Sensor & lens | 1 | PMW3610 | 
| VR | Regulator | 1 |  3.3V input 1.8 or 1.9V output  |
| C3、C4、C5 | Capacitor  | 3 | 0.1uF X7R |
| C6、C7 | | 2 | 0.01uF X7R | 
| C8 | | 1 | 10uF X7R | 
| C9 | | 1 | 3.3uF 16V | 
| C in | | 1 | input capacitor |
| C out | | 1 | output capacitor | 
| R | Resistor | 1 | 10kΩ | 
| | Mouse sole  | 5 | 0.65mm and 0.8mm thickness confirmed| 

### 1.5 Optional

| Types | Quantitie  | |
| --- | --- | --- |
| PH connector Post Side type 2P | 1| For use with batteries with PH connector. Choose a smaller battery. Be sure to check the plus and minus.|
| Choc V1/V2 keyswitches | 10  | Height can be reduced. Sockets and top plates are not used. It cannot coexist with MX switches. Not suitable for holding and using due to the possibility of short-circuiting as described below. |
| Tape or glue | 1 | When using Choc switches, isolate the head of the pin header to prevent unexpected operation. |
| [3-keys blocker](stl/) | 1 | Blocks the palm of the hand when held. |
| [Switch plate](stl/) | 1 | 3DP switch plate with invisible pin header heads. |
| Strap | | |

### 1.6 Tools required
  

| Types                                                | 
| --------------------------------------------------- |
| Soldering iron                                               |
| Trowel                     |
| Soldering wire |
| Nipper                     | 
| Cutter                    |
| File                      | 
| Twezers                    |   
| screwdriver                 | 

### 1.7 Tools optional

| Types                               | 
| --------------------------------- | 
| C-type trowel tip                             | 
| flux|                    |
| IPA                               | 
| Heat-resistant mat                             | 
| Multimater                              |
| Desoldering wire                         | 
| Design Knife                           |
| Masking tape                          | 

## 2 Preparation for assembly

### 2.1 Disconnect the mainboard

It can be split cleanly by cutting a slit with a cutter and bending it.
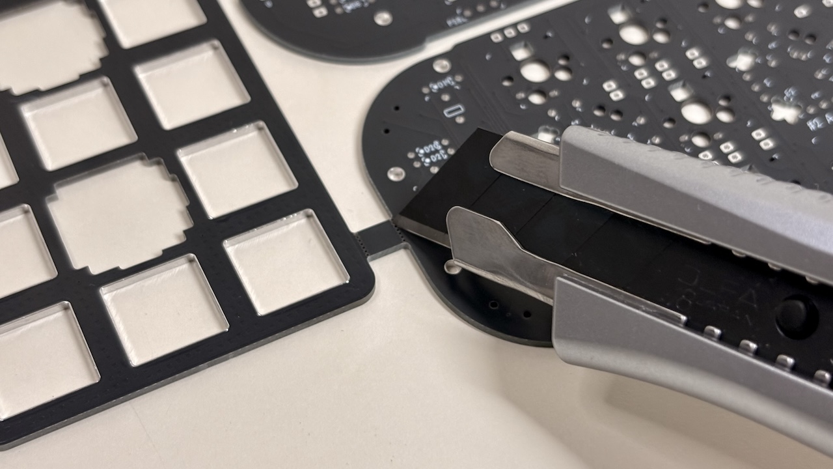
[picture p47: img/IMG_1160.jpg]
  
The tabs are cut away with nippers and the cut surfaces are sanded. Be careful not to remove the original board edges, as over-shaving will damage the circuitry.
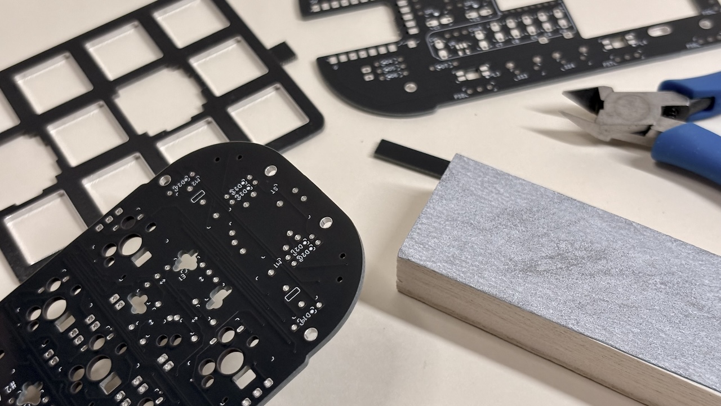
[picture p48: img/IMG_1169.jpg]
  
This area can be left jagged without affecting the finished form.
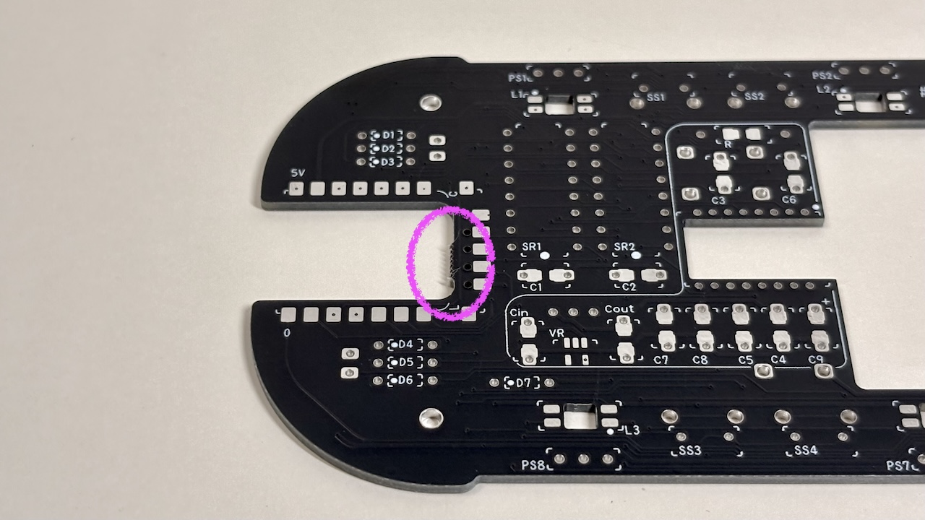
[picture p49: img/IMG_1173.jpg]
  
It could be divided into three parts: main board #1, main board #2 and switch plate.
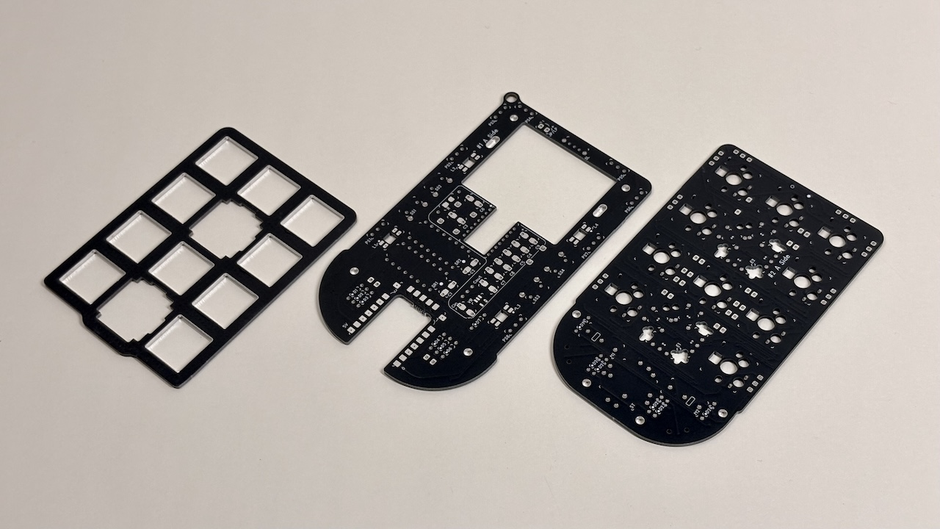
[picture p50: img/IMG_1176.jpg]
  

### 2.2 Remove parts from the runner

Runner I has 3 components and runner II has 17 components.
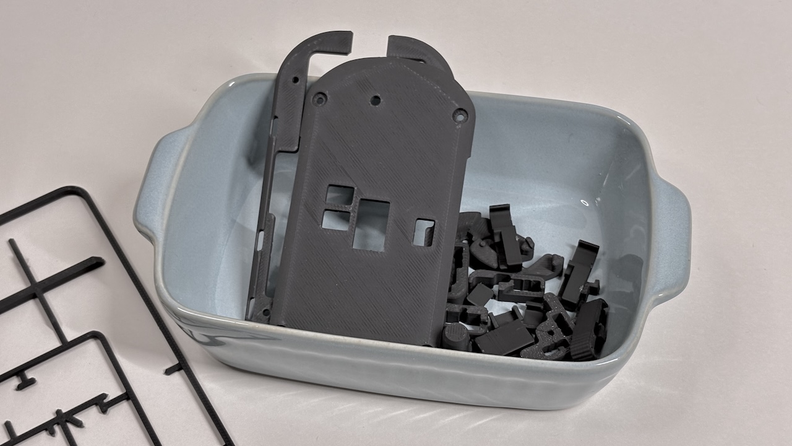
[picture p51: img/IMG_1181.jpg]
  

### 2.3 Remove the shift register and rotary encoder from the case

The shift register is pressed from the back with the runner II component (leverage). Be careful not to prick your finger with the pin.  
For the rotary encoder, cut the left and right claws with nippers.
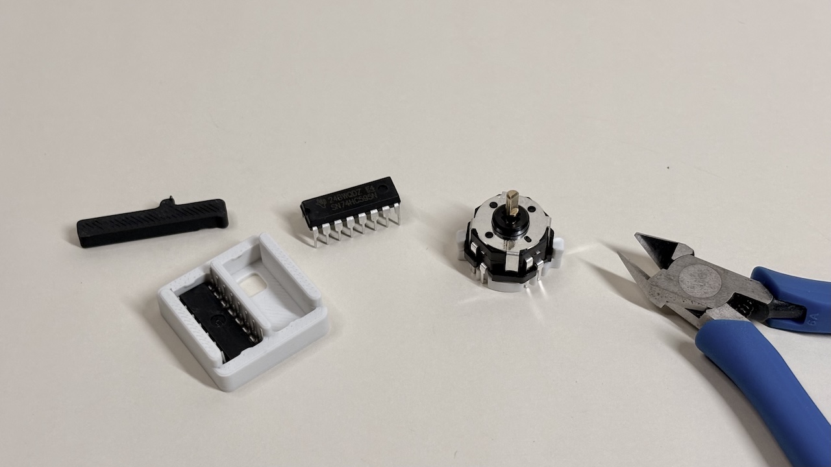
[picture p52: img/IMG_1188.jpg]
  

### 2.4 Write firmware

Download the uf2 file here. There are two types, differing in direction.

- [rmk-cannonball-ll.uf2](https://github.com/Taro-Hayashi/Cannonball-LL/releases/download/0.31.3/rmk-cannonball-ll.uf2)
- [rmk-cannonball-ll-sensor-rotated-180.uf2](https://github.com/Taro-Hayashi/Cannonball-LL/releases/download/0.31.3/rmk-cannonball-ll-sensor-rotated-180.uf2)

Once the XIAO BLE is connected to the PC via the USB cable, press the small reset button twice quickly.
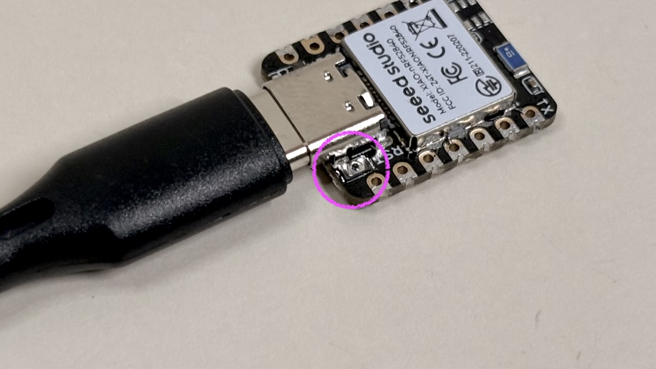
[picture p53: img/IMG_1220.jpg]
    
Drag and drop the uf2 file as it is recognised as a XIAO-SENSE drive.  
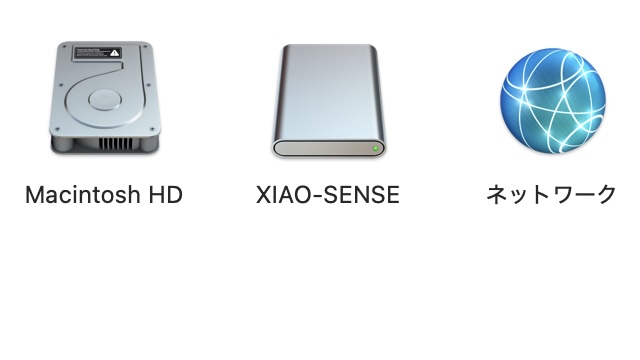
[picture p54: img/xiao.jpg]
    
It will now be recognised as a keyboard.

### 2.5 Press fitting of insert nuts

Press-fit the insert nut into the printed item in the image. Main board #1 is also used.
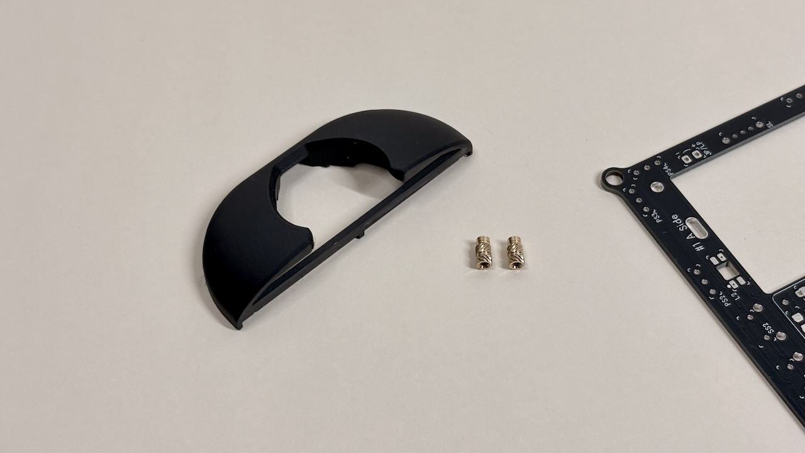
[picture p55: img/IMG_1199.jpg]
  
Apply main board #1 to the backside and press the soldering iron onto the insert nut.
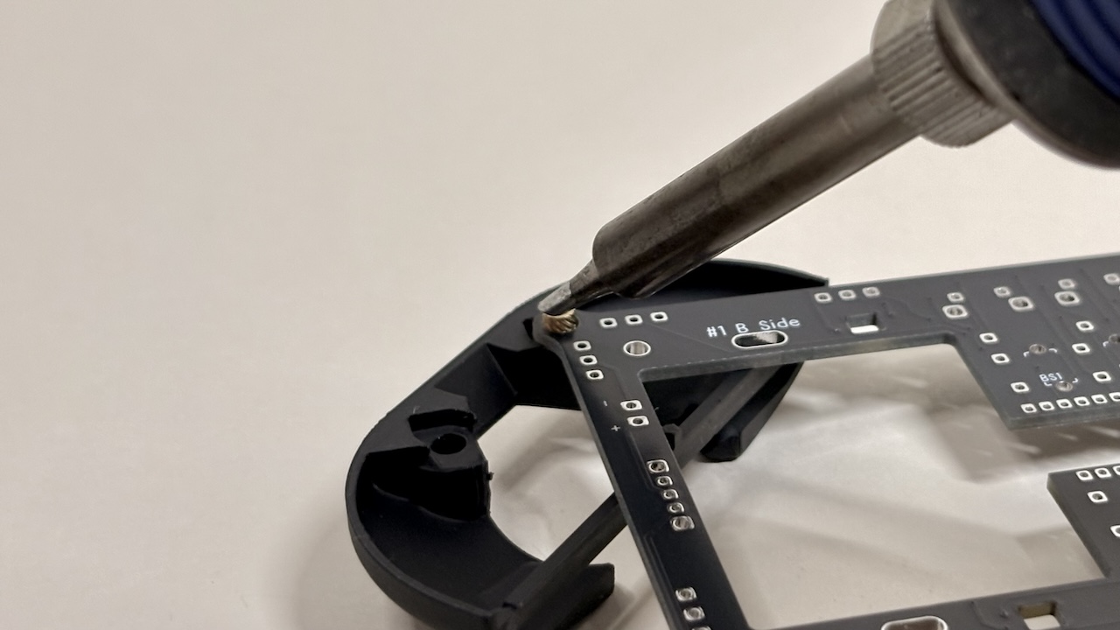
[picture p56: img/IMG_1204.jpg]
  
Ensure as few steps as possible with main board #1.
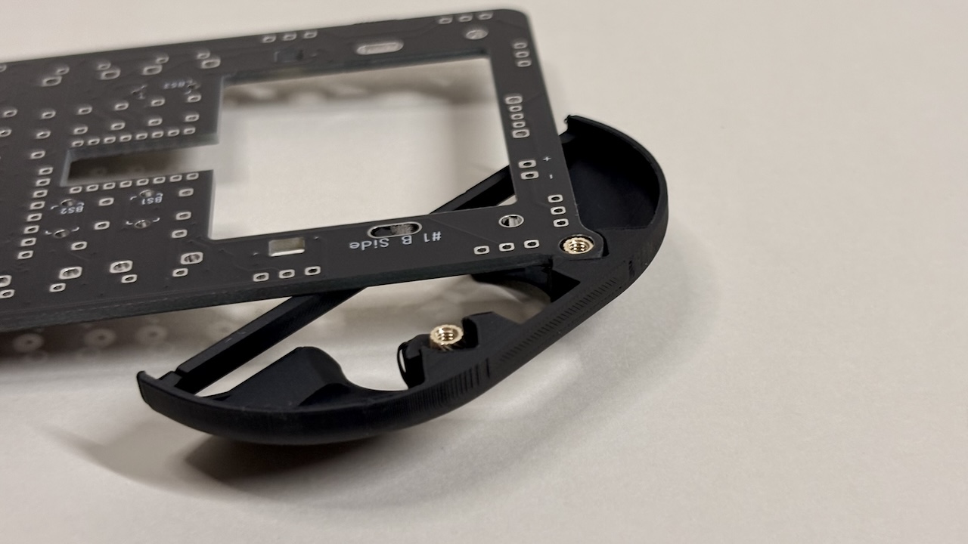
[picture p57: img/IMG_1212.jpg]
  
Cut out the reinforcement with nippers.
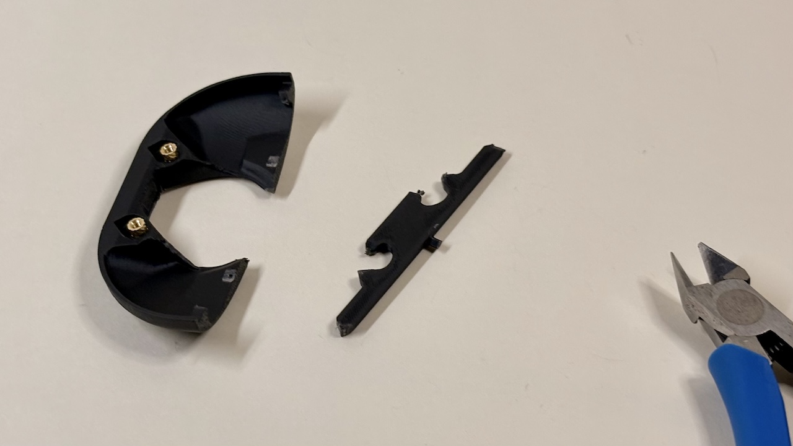
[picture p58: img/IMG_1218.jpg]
  

## 3 Soldering of main board #️1

- The pin headers that may come with the XIAO BLE are thinner than those included and should be discarded to avoid confusion.
- In this build manual, priority is given to checking the operation, and the mouse-ising components are put off until later, but it is easier to solder from the shortest components first.

### 3.1 Be careful when soldering

Imagine molten solder spreading only on the pad due to surface tension. It is very easy to apply flux.
  
Heat the pads and component legs well to allow electricity to pass through both the board and the components.  
Be careful that the solder does not connect with the small holes (VIA).
  
Take care that the legs coming out of the through-hole component are around 2 mm; if they exceed 2.5 mm, they may interfere with the 3D printed item on the bottom.  
It is easier to fix them with masking tape after insertion and soldering.
  
Also, the melting point of 3D printed products is around 200°C. Be careful not to melt the soldering iron if it comes into direct contact with it.

### 3.2 Soldering XIAO BLE

5 V (VUSB), solder the device in the GP0 position, making sure it is on the reverse side.
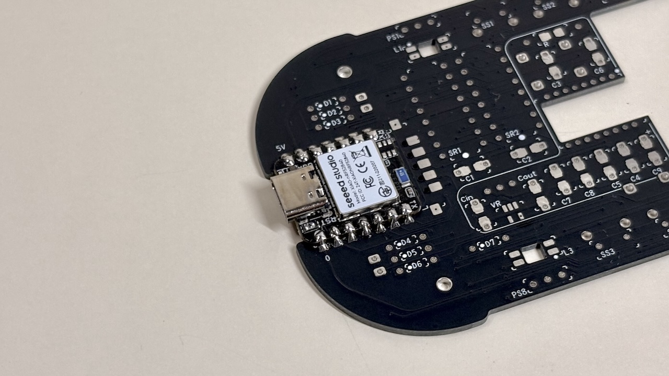
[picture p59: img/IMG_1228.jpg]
  
Wire the RESET to hole 1 and BAT+ to hole 2 on the back.  
Be careful not to pull on the wiring material or consider not soldering the RESET pad, as if it is stripped, the reset button will also be unusable (resetting with the back button will not be possible).
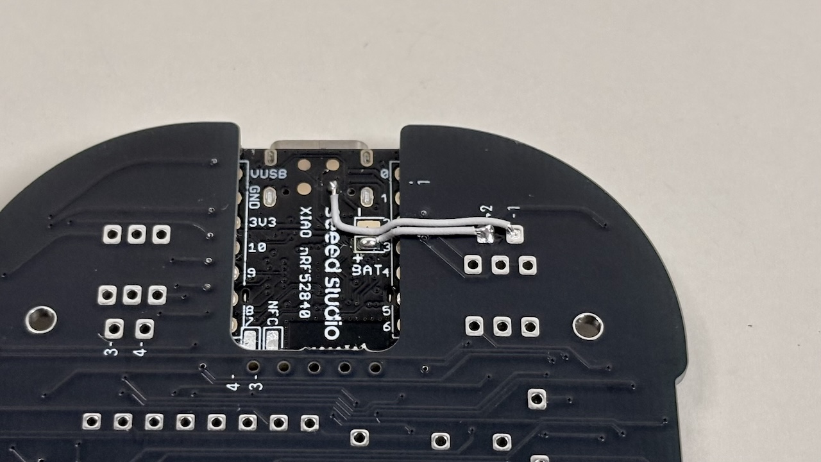
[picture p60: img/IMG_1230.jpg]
  
(Optional) If you want to convert it to a mouse, you also wire two NFC's, 3 to 3 and 4 to 4.
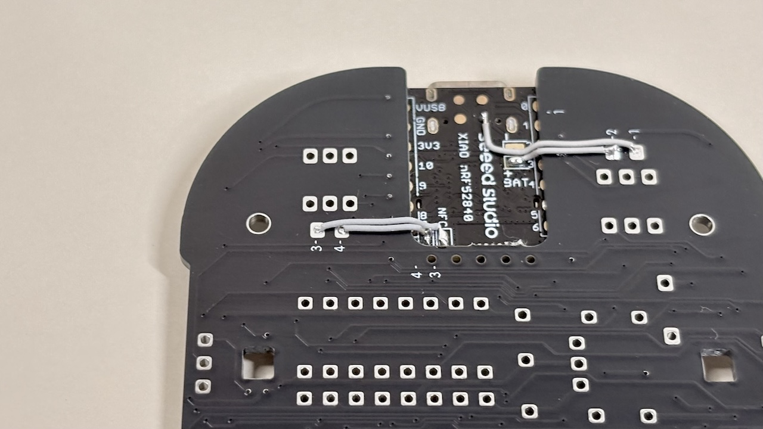
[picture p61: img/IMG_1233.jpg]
  
Take care not to interfere with runner I components.
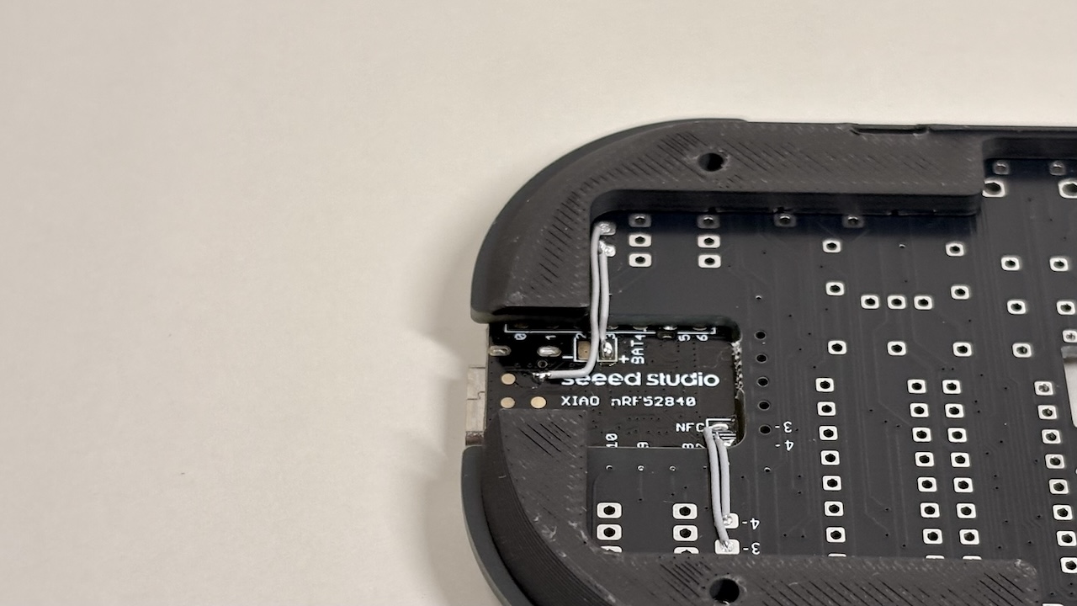
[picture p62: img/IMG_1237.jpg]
  

### 3.3 Soldering of diodes and shift registers

Solder D1 to D7, SR1 and SR2 using the marks as landmarks.
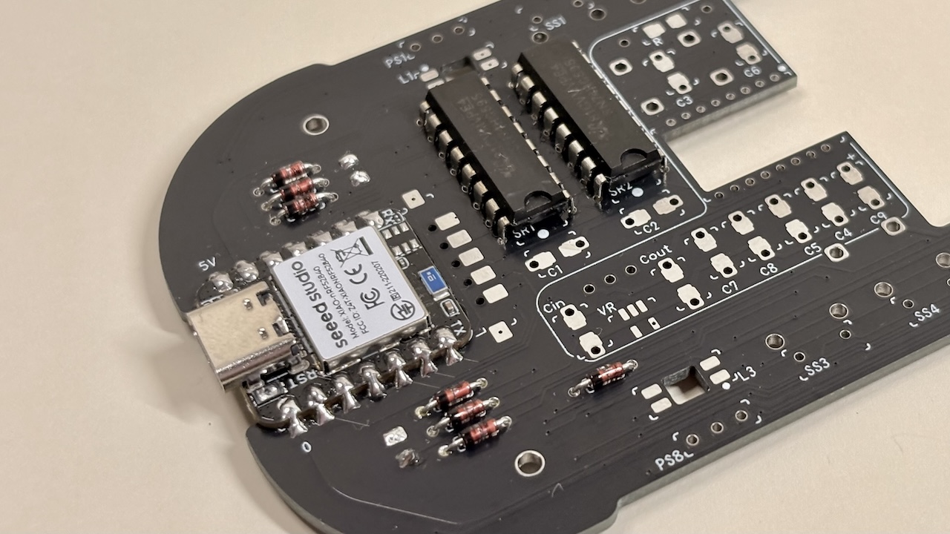
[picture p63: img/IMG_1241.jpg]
  

### 3.4 Soldering of capacitors

Solder to C1 and C2, marked 104. The ones in the sensor set are slightly smaller and have different characteristics, so be careful not to make a mistake.
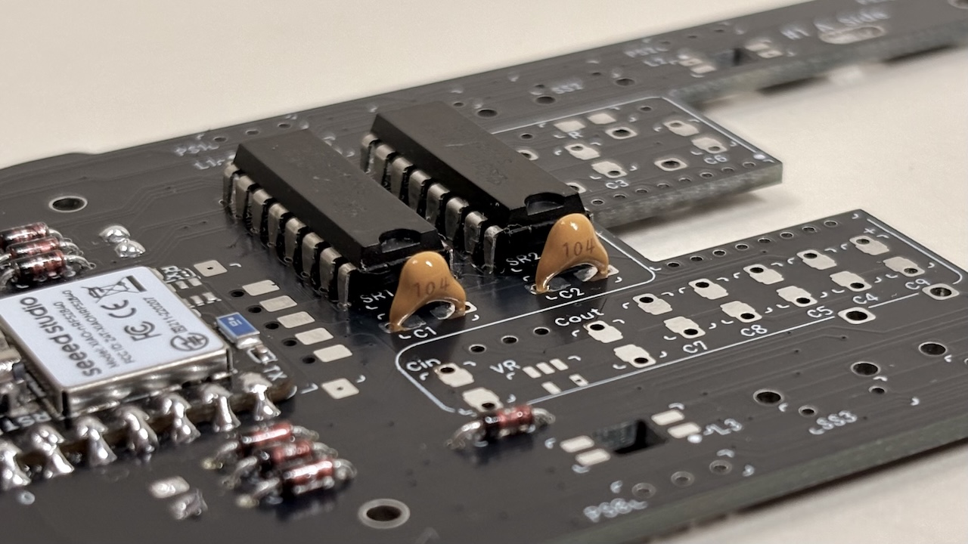
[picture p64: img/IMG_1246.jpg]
  

### 3.5 Soldering side buttons and slide switches

Plug and solder the four side buttons SS1 to SS4 and one slide switch to SL.
  

### 3.6 Soldering of back buttons

The back button is inserted from the backside.
  

### 3.7 Confirmation of operation

Connect to a PC with a USB cable and check the operation of the side buttons and two of the back buttons in a row.
  
Press the remaining back button twice quickly to make sure the XIAO-SENSE drive comes out. This is used for firmware updates.
  
After checking, disconnect the cable. The slide switch is used to switch the battery on and off.

### 3.8 (Optional) Soldering of components for mouseisation

Solder the regulator to VR, capacitors C3 to C9, Cin, Cout and resistor R in the white box.
  
The 3.3uF 16V capacitor on C9 has polarity, so check it before soldering.
  
The regulator of the sensor set is flat side down.
  
Lead-type components are laid down after soldering.
  
Solder the sensor. Align the silk print with the small mark.
  
Remove the sticker from the back, place the lens on it and melt the surface foot to lightly fix it in place.
  
  
Match the runner I components and connect them to the PC to check that the sensor responds.
  
If it does not work, check that the condenser is not wrong or that the legs are not bridged.
Be careful not to damage the lens while working.

### 3.9 Soldering of pin sockets

Cut out eight pin sockets and pin headers with three pins each.
  
Insert the short end of the pin header into the pin socket and place the pin socket side on main board #1.
  
Insert the six Runner II components. If they are difficult to insert, shave off the cut marks on the pin headers or pin sockets.
  
Cover the main board #2 with the pin headers (do not solder yet). If it is difficult to get all the pin headers through, force a few at a time to avoid rubbing the board.
  
Once flipped over, solder the pin socket to main board #1.
  
After soldering is complete, return to the front and remove main board #2.  
Printed items do not need to be removed.
  
If mainboard #2 has been soldered in place, use leverage to remove it. Be aware that if the pin header is bent, it may cause poor contact, so pull it out vertically.
  
If a multimater is available, check that there is continuity between the XIAO BLE, the shift register GPIO and the pin headers.
(The battery is in the picture because the photo was taken later.)
  

### 3.10 Battery soldering

Ensure that the slide switch is in the same condition as in the picture and solder the battery.
  
Make sure to check + and -. After soldering is finished, turn the slide switch on and check that it can be connected to a Bluetooth-enabled device.
  
If you have connection difficulties even though the board is activated, reset the board once with this firmware and then re-install the test firmware.

- [settings_reset-seeeduino_xiao_ble-zmk.uf2](https://github.com/Taro-Hayashi/Cannonball-LL/releases/download/0.28.2/settings_reset-seeeduino_xiao_ble-zmk.uf2)
  
## 3.11 Assembling the lower half

Weld the part for the RP2040-Zero reset button in the small hole in the runner I component.
  
Combine the parts of runner I and place four parts of runner II. Pay attention to the orientation of the central component.
  
(optional) If a sensor is attached, the centre should be a combination of these two parts.
  
(optional) If a sensor is attached, the corner of the button stopper to be placed here interferes, so use nippers to cut it slightly at an angle.
  
Place mainboard #1 on top and fit a nut on one of the corner components of runner I.
  
A total of 9 runner I components and 4 nuts were fitted with long screws.
  
Attach the mouse sole to the back and store in a safe place.
  

## 4 Soldering of mainboard #2

### 4.1 Soldering of diodes

Solder D8 to D24; from D19 onwards the mounting surface is different.
  
  

### 4.2  Soldering of MX sockets

Solder from S1 to S10.
  

### 4.3  Soldering of lever buttons

Attach to L1 and L2. Solder the contacts on the sides as well.
  

### 4.4 Soldering of mouse buttons

Attach to M1 and M2. Align the click bar with the silk print.
  

### 4.5 Assembling the 1U wheel encoder

The following components of the sachet are used.
  

| | Types | Quantities| |
| --- | --- | --- | --- |
| 1 | Wheel | 2 | |
| 2 | Shaft | 2 | |
| 3 | Spacer | 2 | |
| 4 | Base | 2 | |
| 5 | Cover | 2 | |
| 6 | Wheel Encoder | 2 | 6x6x7 |
| 7 | tactile Button | 2 | 11mm |
| 8 | Short screws | 4 | M2 5mm or 6mm |
| 9 | Nut | 4 | M2 |

Solder the tactile button and wheel encoder to E1 and E2 in the orientation chosen. The build guide uses the orientation shown in the image.
  
Insert the shaft from the flat side of the wheel.
  
Attach the wheel to the encoder. Ensure that the hexagonal holes align with the hexagonal shaft.
  
Fit the spacer and place it on the tactile button.
  
Attach the base with screws and nuts.
  
Install the cover.
  

### 4.6 Soldering rotary encoders

Solder to ST.
  

### 4.7 Installing the top cover

Attach from the back side with short screws.
  
Ensure that the mouse buttons are clickable.
  

### 4.8 Soldering of pin headers

Check the orientation and soldering of the components on main board #2 again.
Protect the area on the back of mainboard #2 where the battery hits with tape or a rubber sheet.
  
Place on mainboard #1 and solder the pin headers.
  
Working one by one, starting with the corner pin headers, while trying to reduce the gaps as much as possible, will produce a clean result.

### 4.9 Checking the operation

Attach the shaft from Runner I to the rotary encoder.
  
Connect to a PC to check operation. Check the operation of the socket with one of the keyswitches. Be careful not to break the leg of the keyswitch.
  
After checking operation, disconnect the USB cable.

### 4.10 Installing the switch plate
Align the switch plate with main board #2 and install the keyswitch.
  
The keycap and knob cover are completed when fitted.
  

## 5 Connect to VIAL
Key mapping can be customized using VIAL. It can be connected even when wireless.
- https://vial.rocks/
  
When switched to Layer 1, moving the mouse scrolls the screen.  
  
You can configure cursor and scroll speeds using User Key, as well as save and restore these settings. The settings saved in Slot 1 will be applied when the device is connected.  
  
CPI+/-: Change cursor speed  
CSRTG: Disable curso  
SNIPE: Low speed while button is held down  
SCR+/-: Change scroll speed  
SCRIX/Y: Reverse scroll direction  
SAV1/2: Save to slot  
LOD1/2: Load from slot  

This button on the back is the reset button; pressing it twice will enter bootloader mode.
  

## 6 Misc

### 6.1 Maintenance

If the knob becomes loose or the 1U wheel encoder cover comes off easily, it can be adjusted and fixed by melting it with a soldering iron.  
If the top and bottom fastenings become loose or poor contact, consider replacing the pin headers and pin sockets.

### 6.2 About unused pads

These pads are connected to the LEDs and the centre push.
  

### 6.3 RMK Firmware
- https://github.com/Taro-Hayashi/rmk-cannonball-ll]

reset
- [reset-bootloader.uf2](https://github.com/Taro-Hayashi/Cannonball-LL/releases/download/0.31.3/reset-bootloader.uf2)

### 6.4 ZMK Firmware
- https://github.com/Taro-Hayashi/zmk-config-th/tree/Cannonball-LL

### 6.5 Data for 3D Printing

- [Data for 3D Printing](/stl)

Optional or colour-changed parts can be printed.
    
  
### 6.6 Thanks

I referred to snize([@snize](https://x.com/snize))'s SEIBOKU for the selection of components and the firmware code of pmw3610.

- https://github.com/snize/BOB-PMW3610-SEIBOKU

### 6.7 Sales
- Yushakobo: https://shop.yushakobo.jp/en/products/10537
- Booth: https://tarohayashi.booth.pm/items/6736492

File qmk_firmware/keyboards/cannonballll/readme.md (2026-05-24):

# Cannonball LL

- Manual (English): https://github.com/Taro-Hayashi/Cannonball-LL/blob/main/README.md
- Manual (日本語): https://note.com/taro_hayashi/n/n3da1e116aa8d
- Booth: https://tarohayashi.booth.pm/items/6736492



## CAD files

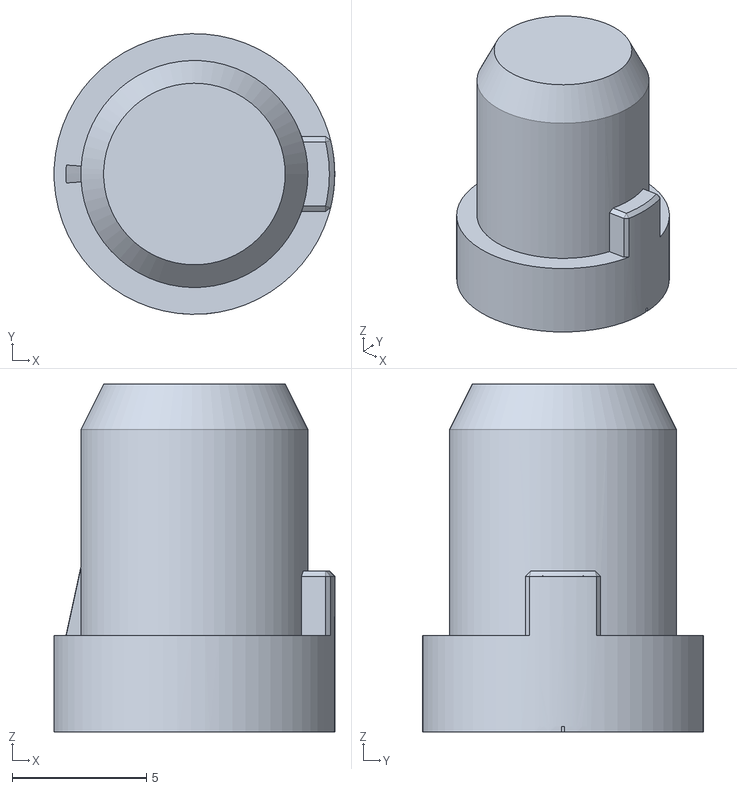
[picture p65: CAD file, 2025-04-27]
stl/included/Shaft.stl
10.4 x 10.5 x 13.0

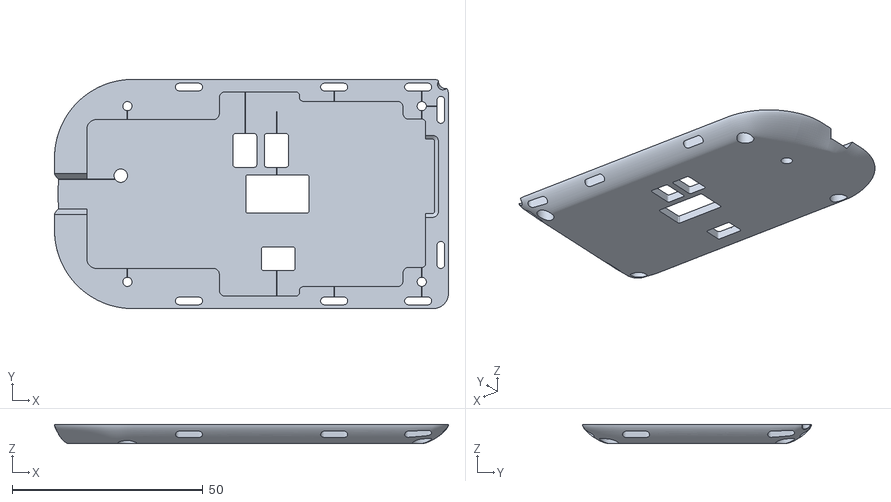
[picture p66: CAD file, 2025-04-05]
stl/optional/Bottom.stl
103.2 x 60.0 x 5.00

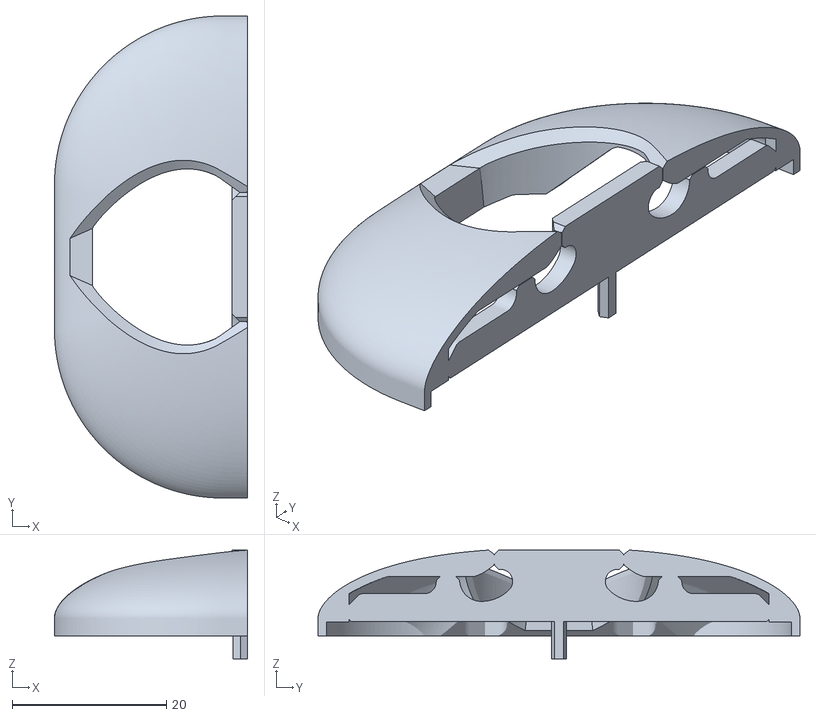
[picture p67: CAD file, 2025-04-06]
stl/included/Top Cover.stl
25.0 x 62.4 x 14.1

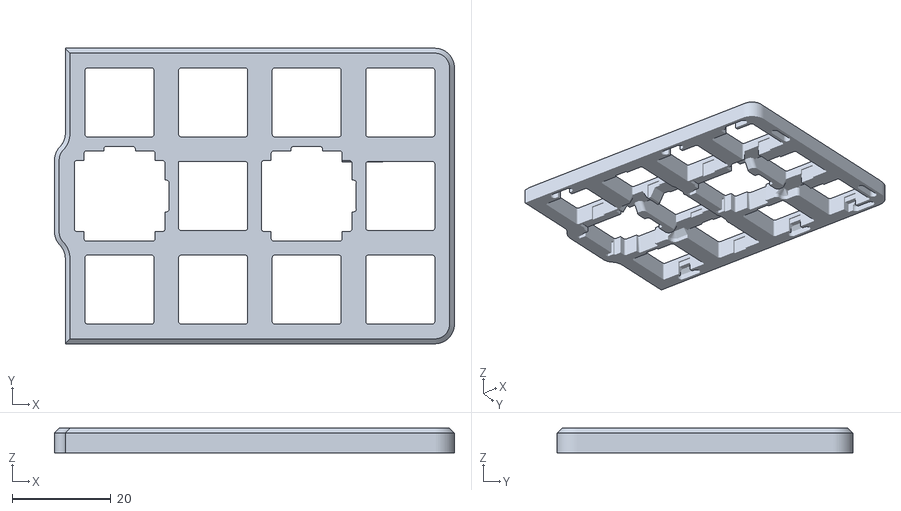
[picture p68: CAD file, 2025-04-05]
stl/optional/Switch plate.stl
81.2 x 60.0 x 5.00

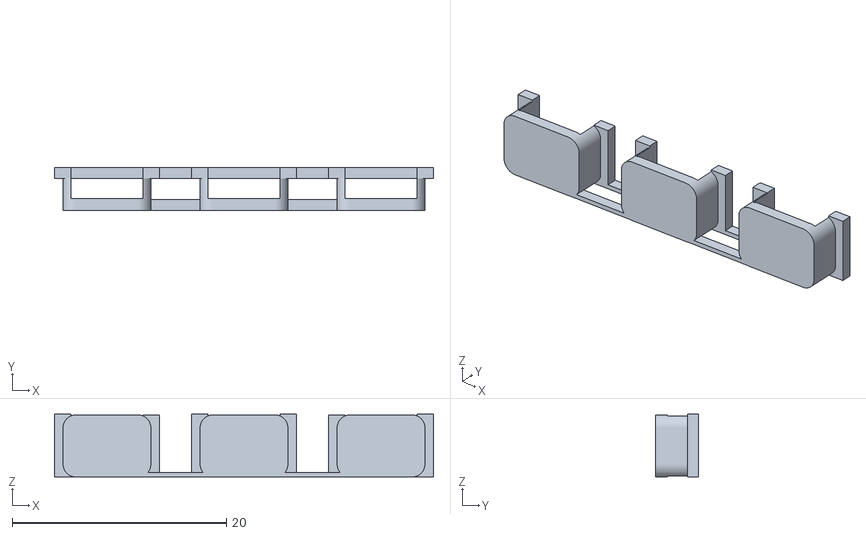
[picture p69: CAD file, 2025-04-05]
stl/included/Bottom Button.stl
35.4 x 4.00 x 5.88

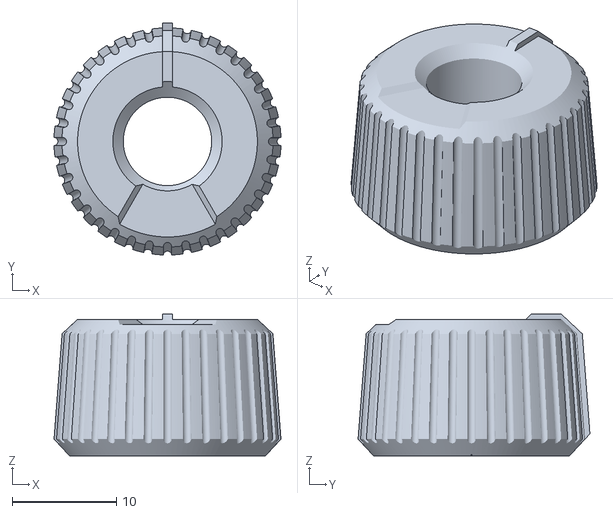
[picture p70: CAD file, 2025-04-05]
stl/optional/Mech Knob.stl
21.7 x 22.2 x 13.6

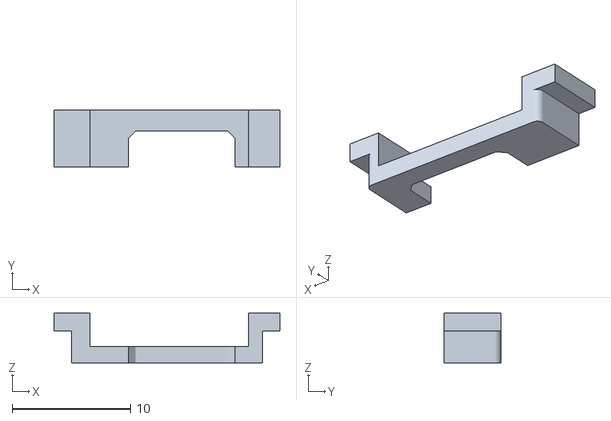
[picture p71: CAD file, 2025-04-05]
stl/included/Sensor Cover #1.stl
19.1 x 4.80 x 4.20

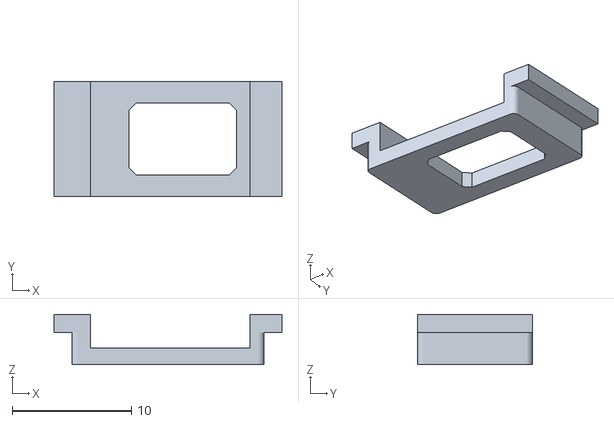
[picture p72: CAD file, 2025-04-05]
stl/optional/Sensor Cover.stl
19.1 x 9.60 x 4.20

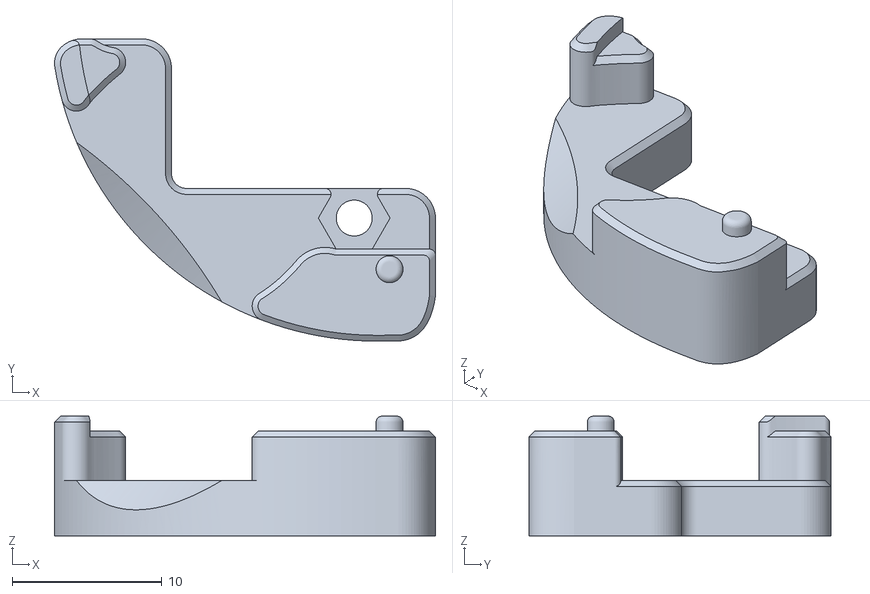
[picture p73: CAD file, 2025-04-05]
stl/included/Side #2.stl
25.5 x 20.2 x 8.00

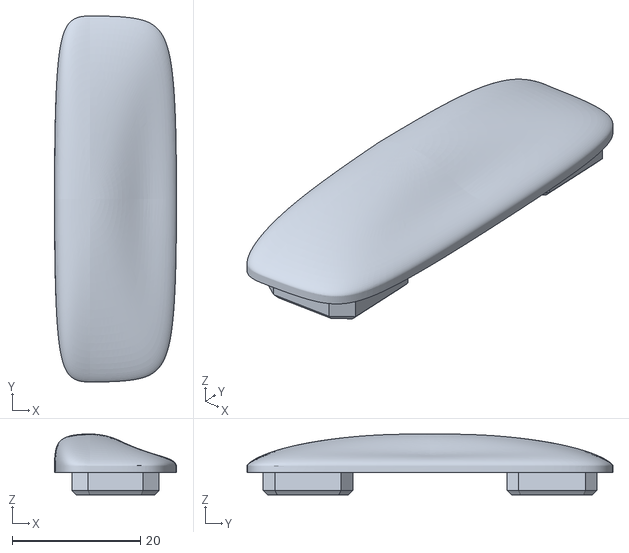
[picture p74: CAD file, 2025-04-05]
stl/optional/3-Key blocker.stl
19.0 x 57.0 x 9.49

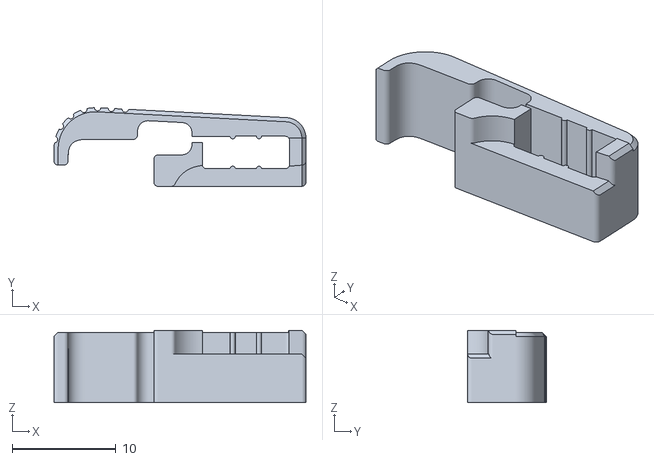
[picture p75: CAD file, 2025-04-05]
stl/included/Side #5.stl
24.3 x 7.60 x 7.00

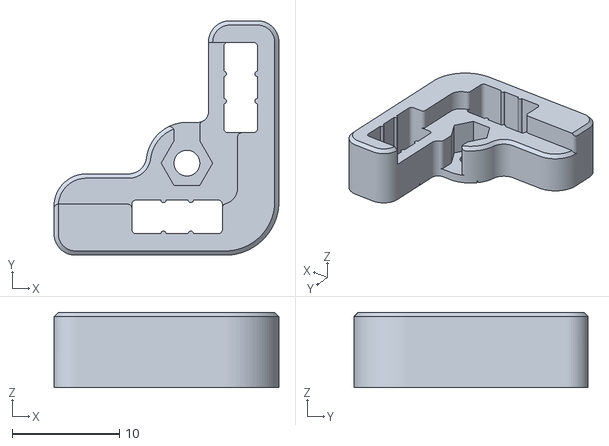
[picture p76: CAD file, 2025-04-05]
stl/included/Side #8.stl
20.9 x 21.8 x 7.00

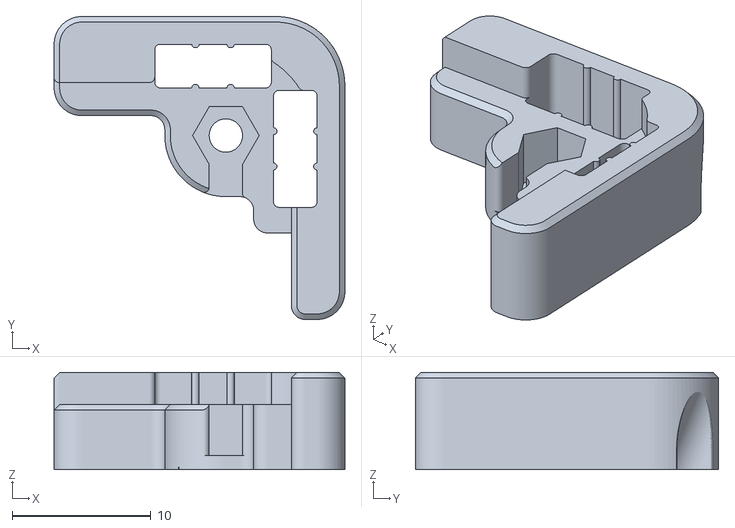
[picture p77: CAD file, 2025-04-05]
stl/included/Side #7.stl
20.9 x 21.8 x 7.00

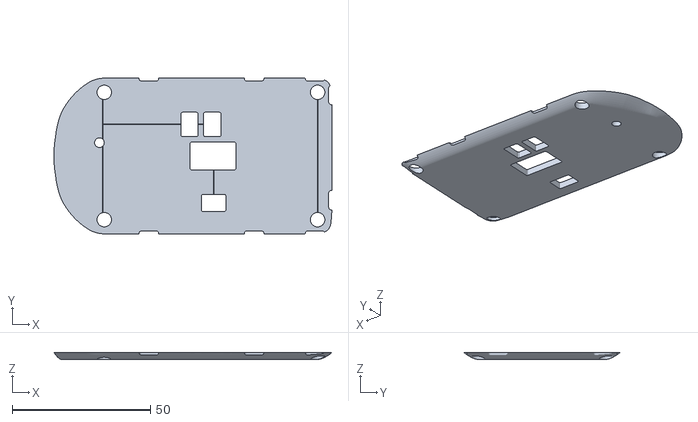
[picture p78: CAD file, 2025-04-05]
stl/included/Bottom #2.stl
100.4 x 56.4 x 2.50

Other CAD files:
stl/included/Side #3.stl
stl/included/Side #4.stl
stl/included/Bottom #1.stl
stl/included/Blocker.stl
stl/included/Reset Button.stl
stl/included/Sensor Cover #2.stl
stl/included/Side #1.stl
stl/included/Side #6.stl
stl/included/Side #9.stl

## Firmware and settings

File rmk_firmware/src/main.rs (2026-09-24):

#![no_std]
#![no_main]

mod keymap;
mod nrf_flex;
mod pointing_slots;
mod sleep;
mod vial;

use defmt::unwrap;
use defmt_rtt as _;
use embassy_embedded_hal::shared_bus::asynch::spi::SpiDevice;
use embassy_executor::Spawner;
use embassy_nrf::gpio::{Flex, Input, Level, Output, OutputDrive, Pull};
use embassy_nrf::peripherals::{RNG, USBD};
use embassy_nrf::usb::Driver;
use embassy_nrf::usb::vbus_detect::HardwareVbusDetect;
use embassy_nrf::{bind_interrupts, pac, rng, usb};
use embassy_sync::blocking_mutex::raw::ThreadModeRawMutex;
use embassy_sync::mutex::Mutex;
use keymap::{
    COL, ROW, SCROLL_LAYER, USER_CPI_DOWN, USER_CPI_UP, USER_CURSOR_TOGGLE, USER_LOAD_SLOT_1,
    USER_LOAD_SLOT_2, USER_SAVE_SLOT_1, USER_SAVE_SLOT_2, USER_SCROLL_INVERT_X,
    USER_SCROLL_INVERT_Y, USER_SCROLL_SPEED_DOWN, USER_SCROLL_SPEED_UP, USER_SNIPE,
};
use nrf_flex::NrfFlex;
use nrf_mpsl::Flash;
use pointing_slots::{
    PointingSettingsSnapshot, SharedFlash, SharedFlashMutex, load_slot, save_slot,
};
use nrf_sdc::mpsl::MultiprotocolServiceLayer;
use nrf_sdc::{self as sdc, mpsl};
use panic_probe as _;
use rand_chacha::ChaCha12Rng;
use rand_core::SeedableRng;
use rmk::ble::build_ble_stack;
use rmk::channel::USER_KEY_EVENT_CHANNEL;
use rmk::config::{
    BehaviorConfig, BleBatteryConfig, DeviceConfig, PositionalConfig, RmkConfig, StorageConfig,
    VialConfig,
};
use rmk::debounce::fast_debouncer::FastDebouncer;
use rmk::driver::bitbang_spi::BitBangSpiBus;
use rmk::event::{PointingSetCpiEvent, publish_event};
use rmk::futures::future::join5;
use rmk::input_device::Runnable;
use rmk::input_device::pmw3610::{Pmw3610, Pmw3610Config};
use rmk::input_device::pointing::{
    PointingDevice, PointingProcessor, PointingProcessorConfig, PointingRuntimeState,
    PointingRuntimeStateCell,
};
use rmk::input_device::rotary_encoder::RotaryEncoder;
use rmk::keyboard::Keyboard;
use rmk::matrix::hc595_matrix::Hc595Matrix;
use rmk::{HostResources, KeymapData, initialize_keymap_and_storage, run_all, run_rmk};
use static_cell::StaticCell;
use vial::{VIAL_KEYBOARD_DEF, VIAL_KEYBOARD_ID};

// --- Pointing tunables (7-step tables, center = firmware default) ---
const CPI_STEPS: [u16; 7] = [400, 600, 900, 1200, 1600, 2100, 2800];
const SCROLL_DIVISOR_STEPS: [u8; 7] = [8, 12, 18, 24, 36, 54, 72];
const DEFAULT_CPI_STEP: u8 = 3;
const DEFAULT_SCROLL_STEP: u8 = 3;
const PMW_DEVICE_ID: u8 = 0;

static POINTING_RUNTIME: PointingRuntimeStateCell = PointingRuntimeStateCell::new(PointingRuntimeState {
    cursor_enabled: true,
    scroll_divisor: SCROLL_DIVISOR_STEPS[DEFAULT_SCROLL_STEP as usize],
    scroll_invert_wheel: false,
    scroll_invert_pan: false,
});

bind_interrupts!(struct Irqs {
    USBD => usb::InterruptHandler<USBD>;
    RNG => rng::InterruptHandler<RNG>;
    EGU0_SWI0 => nrf_sdc::mpsl::LowPrioInterruptHandler;
    CLOCK_POWER => nrf_sdc::mpsl::ClockInterruptHandler, usb::vbus_detect::InterruptHandler;
    RADIO => nrf_sdc::mpsl::HighPrioInterruptHandler;
    TIMER0 => nrf_sdc::mpsl::HighPrioInterruptHandler;
    RTC0 => nrf_sdc::mpsl::HighPrioInterruptHandler;
});

const UNLOCK_KEYS: &[(u8, u8)] = &[(0, 0), (0, 1)];

const L2CAP_MTU: usize = 251;
const L2CAP_TXQ: u8 = 3;
const L2CAP_RXQ: u8 = 3;

struct DummyCs;

impl embedded_hal::digital::ErrorType for DummyCs {
    type Error = core::convert::Infallible;
}

impl embedded_hal::digital::OutputPin for DummyCs {
    fn set_low(&mut self) -> Result<(), Self::Error> {
        Ok(())
    }

    fn set_high(&mut self) -> Result<(), Self::Error> {
        Ok(())
    }
}

#[embassy_executor::task]
async fn mpsl_task(mpsl: &'static MultiprotocolServiceLayer<'static>) -> ! {
    mpsl.run().await
}

fn build_sdc<'d, const N: usize>(
    p: nrf_sdc::Peripherals<'d>,
    rng: &'d mut rng::Rng<'d, embassy_nrf::mode::Async>,
    mpsl: &'d MultiprotocolServiceLayer,
    mem: &'d mut sdc::Mem<N>,
) -> Result<nrf_sdc::SoftdeviceController<'d>, nrf_sdc::Error> {
    sdc::Builder::new()?
        .support_adv()
        .support_peripheral()
        .support_dle_peripheral()
        .support_phy_update_peripheral()
        .support_le_2m_phy()
        .peripheral_count(1)?
        .buffer_cfg(L2CAP_MTU as u16, L2CAP_MTU as u16, L2CAP_TXQ, L2CAP_RXQ)?
        .build(p, rng, mpsl, mem)
}

fn ble_addr() -> [u8; 6] {
    let ficr = pac::FICR;
    let high = u64::from(ficr.deviceid(1).read());
    let addr = high << 32 | u64::from(ficr.deviceid(0).read());
    let addr = addr | 0x0000_c000_0000_0000;
    unwrap!(addr.to_le_bytes()[..6].try_into())
}

#[embassy_executor::main]
async fn main(spawner: Spawner) {
    // nRF config with DCDC
    let mut nrf_config = embassy_nrf::config::Config::default();
    nrf_config.dcdc.reg0_voltage = Some(embassy_nrf::config::Reg0Voltage::_3V3);
    nrf_config.dcdc.reg0 = true;
    nrf_config.dcdc.reg1 = true;
    let p = embassy_nrf::init(nrf_config);

    // --- MPSL (Multiprotocol Service Layer) ---
    let mpsl_p =
        mpsl::Peripherals::new(p.RTC0, p.TIMER0, p.TEMP, p.PPI_CH19, p.PPI_CH30, p.PPI_CH31);
    let lfclk_cfg = mpsl::raw::mpsl_clock_lfclk_cfg_t {
        source: mpsl::raw::MPSL_CLOCK_LF_SRC_RC as u8,
        rc_ctiv: mpsl::raw::MPSL_RECOMMENDED_RC_CTIV as u8,
        rc_temp_ctiv: mpsl::raw::MPSL_RECOMMENDED_RC_TEMP_CTIV as u8,
        accuracy_ppm: mpsl::raw::MPSL_DEFAULT_CLOCK_ACCURACY_PPM as u16,
        skip_wait_lfclk_started: mpsl::raw::MPSL_DEFAULT_SKIP_WAIT_LFCLK_STARTED != 0,
    };
    static MPSL: StaticCell<MultiprotocolServiceLayer> = StaticCell::new();
    static SESSION_MEM: StaticCell<mpsl::SessionMem<1>> = StaticCell::new();
    let mpsl = MPSL.init(unwrap!(mpsl::MultiprotocolServiceLayer::with_timeslots(
        mpsl_p,
        Irqs,
        lfclk_cfg,
        SESSION_MEM.init(mpsl::SessionMem::new()),
    )));
    spawner.spawn(mpsl_task(&*mpsl).unwrap());

    // --- SDC (SoftDevice Controller) ---
    let sdc_p = sdc::Peripherals::new(
        p.PPI_CH17, p.PPI_CH18, p.PPI_CH20, p.PPI_CH21, p.PPI_CH22, p.PPI_CH23, p.PPI_CH24,
        p.PPI_CH25, p.PPI_CH26, p.PPI_CH27, p.PPI_CH28, p.PPI_CH29,
    );
    static RNG_INST: StaticCell<rng::Rng<'static, embassy_nrf::mode::Async>> = StaticCell::new();
    let rng_inst = RNG_INST.init(rng::Rng::new(p.RNG, Irqs));
    let mut rng_gen = ChaCha12Rng::from_rng(&mut *rng_inst).unwrap();
    static SDC_MEM: StaticCell<sdc::Mem<4096>> = StaticCell::new();
    let sdc_mem = SDC_MEM.init(sdc::Mem::<4096>::new());
    let sdc = unwrap!(build_sdc(sdc_p, rng_inst, mpsl, sdc_mem));

    // --- BLE stack ---
    let mut host_resources = HostResources::new();
    let stack = build_ble_stack(sdc, ble_addr(), &mut rng_gen, &mut host_resources).await;

    // USB driver
    let driver = Driver::new(p.USBD, Irqs, HardwareVbusDetect::new(Irqs));

    // Internal flash (MPSL-aware) shared between rmk storage and slot I/O.
    static FLASH_MUTEX: StaticCell<SharedFlashMutex> = StaticCell::new();
    let flash_mutex: &'static SharedFlashMutex =
        FLASH_MUTEX.init(Mutex::new(Flash::take(mpsl, p.NVMC)));
    let flash = SharedFlash::new(flash_mutex);

    // --- 74HC595 matrix ---
    let row_pins = [
        Input::new(p.P0_28, Pull::Down),
        Input::new(p.P0_29, Pull::Down),
    ];
    let debouncer = FastDebouncer::new();
    let matrix_sck = Output::new(p.P0_05, Level::High, OutputDrive::Standard);
    let matrix_sdio = NrfFlex(Flex::new(p.P0_04));
    let shared_bus = {
        static SPI_BUS: StaticCell<
            Mutex<ThreadModeRawMutex, BitBangSpiBus<Output<'static>, NrfFlex<'static>>>,
        > = StaticCell::new();
        SPI_BUS.init(Mutex::new(BitBangSpiBus::new(matrix_sck, matrix_sdio)))
    };
    let matrix_spi = SpiDevice::new(shared_bus, DummyCs);
    let matrix_cs = Output::new(p.P1_11, Level::High, OutputDrive::Standard);
    let mut matrix = Hc595Matrix::<_, _, _, _, ROW, COL>::new(matrix_spi, matrix_cs, row_pins, debouncer).await;

    // --- PMW3610 trackball (shares the matrix SPI bus) ---
    let pmw_cs = Output::new(p.P0_10, Level::High, OutputDrive::Standard);
    let pmw_spi = SpiDevice::new(shared_bus, pmw_cs);
    let pmw_motion = Input::new(p.P0_09, Pull::Up);
    let pmw_config = Pmw3610Config {
        res_cpi: 1200,
        swap_xy: true,
        invert_x: !cfg!(feature = "sensor-rotated-180"),
        invert_y: cfg!(feature = "sensor-rotated-180"),
        ..Default::default()
    };
    let mut pointing_device =
        PointingDevice::<Pmw3610<_, _>>::new(0, pmw_spi, Some(pmw_motion), pmw_config);

    // --- Rotary encoders ---
    let mut enc_head = RotaryEncoder::new(
        Input::new(p.P0_03, Pull::Up),
        Input::new(p.P0_02, Pull::Up),
        0,
    );
    let mut enc_chest = RotaryEncoder::new(
        Input::new(p.P1_15, Pull::Up),
        Input::new(p.P1_14, Pull::Up),
        1,
    );
    #[cfg(not(feature = "sensor-rotated-180"))]
    let mut enc_leg = RotaryEncoder::new(
        Input::new(p.P1_13, Pull::Up),
        Input::new(p.P1_12, Pull::Up),
        2,
    );
    #[cfg(feature = "sensor-rotated-180")]
    let mut enc_leg = RotaryEncoder::new(
        Input::new(p.P1_12, Pull::Up),
        Input::new(p.P1_13, Pull::Up),
        2,
    );

    // --- RMK config ---
    let storage_config = StorageConfig {
        start_addr: 0xA0000,
        num_sectors: 6,
        clear_storage: false,
        ..Default::default()
    };
    let ble_battery_config = BleBatteryConfig::default();
    let rmk_config = RmkConfig {
        device_config: DeviceConfig {
            vid: 0x8884,
            pid: 0x0919,
            manufacturer: "Taro Hayashi",
            product_name: "Cannonball LL",
            serial_number: "vial:f64c2b3c:000001",
        },
        vial_config: VialConfig::new(VIAL_KEYBOARD_ID, VIAL_KEYBOARD_DEF, UNLOCK_KEYS),
        storage_config,
        ble_battery_config,
        ..Default::default()
    };

    let mut keymap_data = KeymapData::new_with_encoder(
        keymap::get_default_keymap(),
        keymap::get_default_encoder_map(),
    );
    let mut behavior_config = BehaviorConfig::default();
    let per_key_config = PositionalConfig::default();
    let (keymap, mut storage) = initialize_keymap_and_storage(
        &mut keymap_data,
        flash,
        &rmk_config.storage_config,
        &mut behavior_config,
        &per_key_config,
    )
    .await;

    let mut keyboard = Keyboard::new(&keymap);
    let mut pointing_processor = PointingProcessor::new(
        &keymap,
        PointingProcessorConfig {
            scroll_layer: Some(SCROLL_LAYER),
            ..Default::default()
        },
    )
    .with_runtime_state(&POINTING_RUNTIME);

    // Publish the initial CPI so PMW3610 matches the firmware default step.
    publish_event(PointingSetCpiEvent {
        device_id: PMW_DEVICE_ID,
        cpi: CPI_STEPS[DEFAULT_CPI_STEP as usize],
    });

    join5(
        run_all!(matrix, enc_head, enc_chest, enc_leg, pointing_device, pointing_processor),
        keyboard.run(),
        run_rmk(&keymap, driver, &stack, &mut storage, rmk_config),
        pointing_user_key_dispatcher(flash_mutex),
        sleep::sleep_manager(),
    )
    .await;
}

fn set_cpi(step: u8) {
    let cpi = CPI_STEPS[step as usize];
    publish_event(PointingSetCpiEvent { device_id: PMW_DEVICE_ID, cpi });
    defmt::info!("CPI step {} ({} cpi)", step, cpi);
}

fn apply_snapshot(snapshot: PointingSettingsSnapshot) -> Option<(u8, u8)> {
    if snapshot.cpi_step as usize >= CPI_STEPS.len()
        || snapshot.scroll_step as usize >= SCROLL_DIVISOR_STEPS.len()
    {
        return None;
    }
    let divisor = SCROLL_DIVISOR_STEPS[snapshot.scroll_step as usize];
    POINTING_RUNTIME.update(|s| {
        s.cursor_enabled = snapshot.cursor_enabled;
        s.scroll_divisor = divisor;
        s.scroll_invert_wheel = snapshot.scroll_invert_wheel;
        s.scroll_invert_pan = snapshot.scroll_invert_pan;
    });
    set_cpi(snapshot.cpi_step);
    Some((snapshot.cpi_step, snapshot.scroll_step))
}

/// Listens on USER_KEY_EVENT_CHANNEL and mutates pointing runtime state
/// + republishes PMW3610 CPI changes. Snipe saves the active CPI step on
/// press and restores it on release. On startup, loads Slot 1 if present.
async fn pointing_user_key_dispatcher(flash_mutex: &'static SharedFlashMutex) {
    let mut cpi_step: u8 = DEFAULT_CPI_STEP;
    let mut scroll_step: u8 = DEFAULT_SCROLL_STEP;
    let mut snipe_saved_step: Option<u8> = None;

    // Wait for PointingDevice to subscribe to PointingSetCpiEvent before
    // publishing — publish_immediate drops messages when no subscriber exists.
    embassy_time::Timer::after(embassy_time::Duration::from_millis(500)).await;

    // Auto-load Slot 1 on boot; fall back to defaults if absent/invalid.
    let loaded = match load_slot(flash_mutex, 1).await {
        Some(snapshot) => match apply_snapshot(snapshot) {
            Some((c, s)) => {
                cpi_step = c;
                scroll_step = s;
                defmt::info!("Loaded pointing Slot 1 on boot");
                true
            }
            None => {
                defmt::warn!("Slot 1 blob rejected (out-of-range step)");
                false
            }
        },
        None => false,
    };
    if !loaded {
        set_cpi(cpi_step);
    }

    loop {
        let evt = USER_KEY_EVENT_CHANNEL.receive().await;
        match (evt.id, evt.pressed) {
            (USER_CPI_UP, true) => {
                if cpi_step + 1 < CPI_STEPS.len() as u8 {
                    cpi_step += 1;
                    set_cpi(cpi_step);
                }
            }
            (USER_CPI_DOWN, true) => {
                if cpi_step > 0 {
                    cpi_step -= 1;
                    set_cpi(cpi_step);
                }
            }
            (USER_CURSOR_TOGGLE, true) => {
                POINTING_RUNTIME.update(|s| s.cursor_enabled = !s.cursor_enabled);
                let enabled = POINTING_RUNTIME.get().cursor_enabled;
                defmt::info!("Cursor enabled: {}", enabled);
            }
            (USER_SNIPE, true) => {
                if snipe_saved_step.is_none() {
                    snipe_saved_step = Some(cpi_step);
                    cpi_step = 0;
                    set_cpi(cpi_step);
                }
            }
            (USER_SNIPE, false) => {
                if let Some(saved) = snipe_saved_step.take() {
                    cpi_step = saved;
                    set_cpi(cpi_step);
                }
            }
            (USER_SCROLL_SPEED_UP, true) => {
                if scroll_step > 0 {
                    scroll_step -= 1;
                    let divisor = SCROLL_DIVISOR_STEPS[scroll_step as usize];
                    POINTING_RUNTIME.update(|s| s.scroll_divisor = divisor);
                    defmt::info!("Scroll step {} (divisor {})", scroll_step, divisor);
                }
            }
            (USER_SCROLL_SPEED_DOWN, true) => {
                if scroll_step + 1 < SCROLL_DIVISOR_STEPS.len() as u8 {
                    scroll_step += 1;
                    let divisor = SCROLL_DIVISOR_STEPS[scroll_step as usize];
                    POINTING_RUNTIME.update(|s| s.scroll_divisor = divisor);
                    defmt::info!("Scroll step {} (divisor {})", scroll_step, divisor);
                }
            }
            (USER_SCROLL_INVERT_X, true) => {
                POINTING_RUNTIME.update(|s| s.scroll_invert_pan = !s.scroll_invert_pan);
                defmt::info!("Scroll invert X: {}", POINTING_RUNTIME.get().scroll_invert_pan);
            }
            (USER_SCROLL_INVERT_Y, true) => {
                POINTING_RUNTIME.update(|s| s.scroll_invert_wheel = !s.scroll_invert_wheel);
                defmt::info!("Scroll invert Y: {}", POINTING_RUNTIME.get().scroll_invert_wheel);
            }
            (USER_SAVE_SLOT_1, true) => {
                save_current(flash_mutex, 1, cpi_step, scroll_step).await;
            }
            (USER_LOAD_SLOT_1, true) => {
                if let Some((c, s)) = load_and_apply(flash_mutex, 1).await {
                    cpi_step = c;
                    scroll_step = s;
                }
            }
            (USER_SAVE_SLOT_2, true) => {
                save_current(flash_mutex, 2, cpi_step, scroll_step).await;
            }
            (USER_LOAD_SLOT_2, true) => {
                if let Some((c, s)) = load_and_apply(flash_mutex, 2).await {
                    cpi_step = c;
                    scroll_step = s;
                }
            }
            _ => {}
        }
    }
}

async fn save_current(
    flash_mutex: &'static SharedFlashMutex,
    slot: u8,
    cpi_step: u8,
    scroll_step: u8,
) {
    let rt = POINTING_RUNTIME.get();
    let snapshot = PointingSettingsSnapshot {
        cpi_step,
        scroll_step,
        cursor_enabled: rt.cursor_enabled,
        scroll_invert_wheel: rt.scroll_invert_wheel,
        scroll_invert_pan: rt.scroll_invert_pan,
    };
    match save_slot(flash_mutex, slot, snapshot).await {
        Ok(()) => defmt::info!("Saved pointing Slot {}", slot),
        Err(_) => defmt::error!("Save Slot {} failed", slot),
    }
}

async fn load_and_apply(flash_mutex: &'static SharedFlashMutex, slot: u8) -> Option<(u8, u8)> {
    match load_slot(flash_mutex, slot).await {
        Some(snapshot) => match apply_snapshot(snapshot) {
            Some(pair) => {
                defmt::info!("Loaded pointing Slot {}", slot);
                Some(pair)
            }
            None => {
                defmt::warn!("Slot {} blob rejected (out-of-range step)", slot);
                None
            }
        },
        None => {
            defmt::warn!("Slot {} empty or invalid", slot);
            None
        }
    }
}

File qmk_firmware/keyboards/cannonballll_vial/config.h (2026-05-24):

// Copyright 2025 Hayashi (@w_vwbw)
// SPDX-License-Identifier: GPL-3.0-or-later

#pragma once

#define RGBLIGHT_LAYERS_RETAIN_VAL

#define SPI_DRIVER SPID1
#define SPI_SCK_PIN     GP10
#define SPI_MOSI_PIN    GP11
#define SPI_MISO_PIN    NO_PIN
#define SPI_MODE 3

#define SHIFTREG_MATRIX_COL_CS  GP13
#define SHIFTREG_DIVISOR        32
#define SHIFTREG_ROWS           2
#define SHIFTREG_COLS           15

#define MATRIX_ROW_PINS_SR { GP2, GP3 }

//            0x0001, 0x0002, 0x0004, 0x0008, 0x0010, 0x0020, 0x0040, 0x0080, 0x0100, 0x0200, 0x0400, 0x0800, 0x1000, 0x2000, 0x4000, 0x8000
//            1QA     1QB     1QC     1QD     1QE     1QF     1QG     1QH     2QA     2QB     2QC     2QD     2QE     2QF     2QG     2QH
#define COLS {0x0001, 0x0002, 0x0004, 0x0008, 0x0010, 0x0020, 0x0040, 0x0080, 0x0100, 0x0200, 0x0400, 0x0800, 0x1000, 0x2000, 0x4000}

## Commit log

2025-04-05 Update Top Cover.stl
    [Top Cover.stl]
2025-04-17 update stl
    [Shaft.stl]
2026-09-24 Add the RMK firmware for the wireless version
    Firmware for the nRF52840 build, with a GitHub Actions workflow that
    produces UF2 files for the normal and sensor-rotated-180 variants.

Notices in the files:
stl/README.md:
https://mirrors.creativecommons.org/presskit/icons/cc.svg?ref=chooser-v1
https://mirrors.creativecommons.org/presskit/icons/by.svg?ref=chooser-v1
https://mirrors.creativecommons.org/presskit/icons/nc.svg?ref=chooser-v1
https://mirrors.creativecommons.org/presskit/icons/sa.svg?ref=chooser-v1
